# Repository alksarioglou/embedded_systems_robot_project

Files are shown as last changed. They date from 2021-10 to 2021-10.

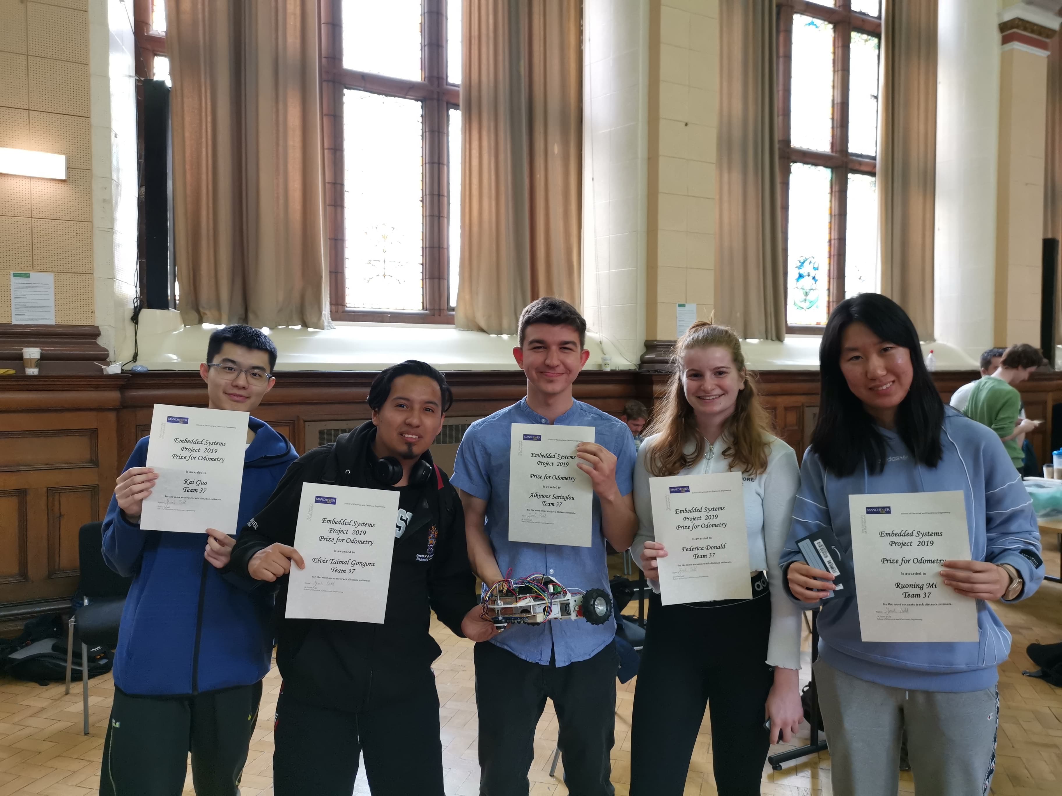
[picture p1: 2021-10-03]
Team.jpg

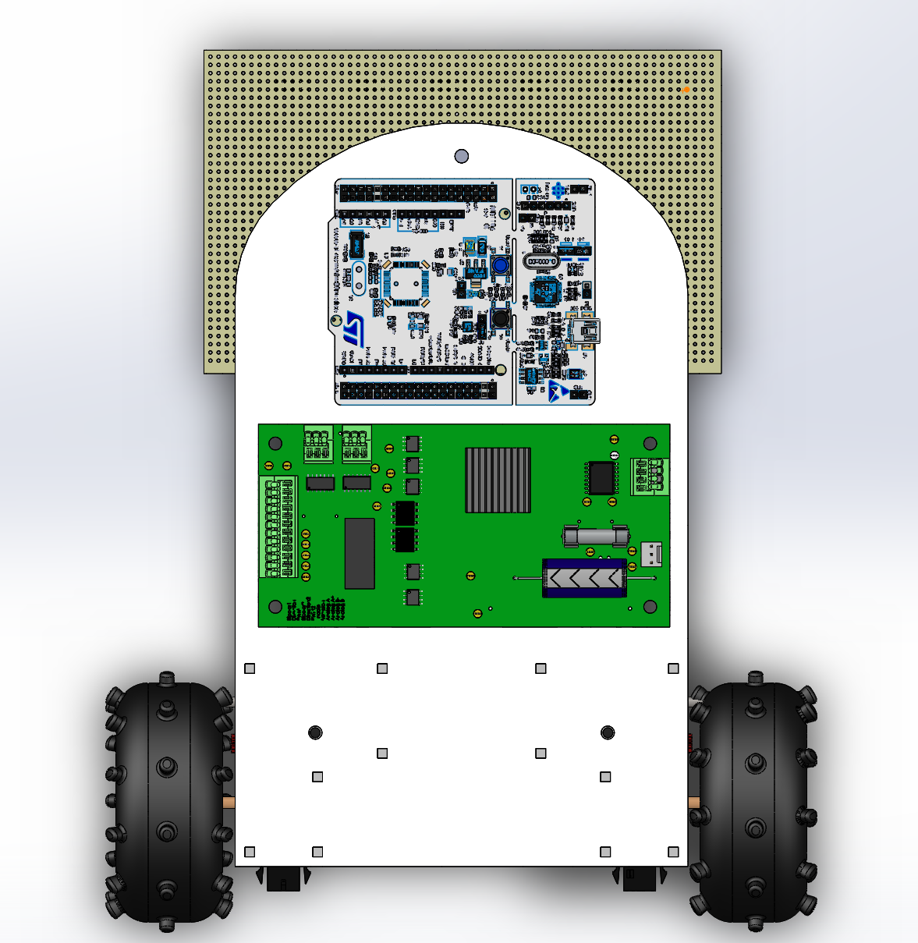
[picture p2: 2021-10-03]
Robot_CAD_Models/5.PNG

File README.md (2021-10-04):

# Embedded Systems Buggy Project
Building an autonomous robot in a team of 5 students which followed a white line on a track using reflective sensors and PID controllers by coding in **Arduino** and **C++**.

## My responsibilities
- **Team leader for both hardware and software** in a team of 5 students 
- Implemented the award-winning algorithm (**Track Length Estimation Award**) in **C++** to measure the distance covered by the robot accurately to 3 decimal places (code found in `Source Code/distancecalc.cpp`)
- Implemented the **coding of the motors, the interface of the sensors and multiple other functions such as steering, stop and turn-around** (code found in `Source Code/FinalCode - Group 37.cpp`)
- Designed the **stripboard** of the reflective sensors (stripboard implementation found in `Schematics`)
- Converted the stripboard to a **PCB** (PCB found in `PCB`)
- Created the **CAD models** for the body of the buggy (models found in `Robot_CAD_Models`)

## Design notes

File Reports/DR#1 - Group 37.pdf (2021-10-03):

## Embedded Systems Project

## DESIGN REPORT #1

## Title: Electric Motor Characterisation and Gear Ratios

## Group Number: 37

Group members name: | ID Number | I confirm that this is the group’s own work.
Alkinoos Sarioglou | 10136315 | ☒
Elvis Taimal Gongora | 10146823 | ☒
Federica Donald | 10095518 | ☒
Kai Guo | 10201372 | ☒
Ruoning Mi | 10431554 | ☒

## Tutor: Dr Emad Alsusa Date: 31/10/2018

Contents

Introduction

This report analyses the measurements taken in the motor characterisation and force laboratory, evaluates their meaning and significance to the characterisation and concludes all the measurements to recommend the final gear ratios for the buggy. This is a crucial part of the embedded systems project as the correct gear ratios must be found for our design to ensure the buggy can move around different terrains, trading off appropriately between torque and speed. A gear box uses efficient gear ratios to provide higher levels of torque for the same mass. However, the speed of the motor is reduced as torque increases so the buggy will not be able to travel around the track as quickly. Furthermore, the microcontroller current is too small to power a motor, so a motor driver is necessary to communicate with the motor and provide the higher currents needed to operate. The microcontroller produces electrical signals and the motor gets mechanical signals that cause it to move. The electrical signal that determines the motor speed is the voltage whilst the current flowing through the motor circuit effects the torque in the input shaft.

Motor characterisation

Introduction
Motor characterisation is an important part of the project as it enables the calculation of the armature resistance, brush voltage and torque constants of the motors.

Constraints on maximum voltage and current The motor drive board can supply a maximum of 1.4 A [1] restricting the values that can be tested. According to Joule’s law（Q =

V

2

R

∗ t) (Equ. 1) [2] where Q is thermal energy, the higher the voltage, the hotter the motor will be. To protect the motor, voltage was set at 5 V [1].

Test results and Calculations

### 2.3.1 Diameter of the shaft

In order to get a more accurate value of the diameter, three measurements were performed, and the average was calculated giving 9.63 mm.

### 2.3.2 Armature Resistance and Brush voltage with Motor stalled

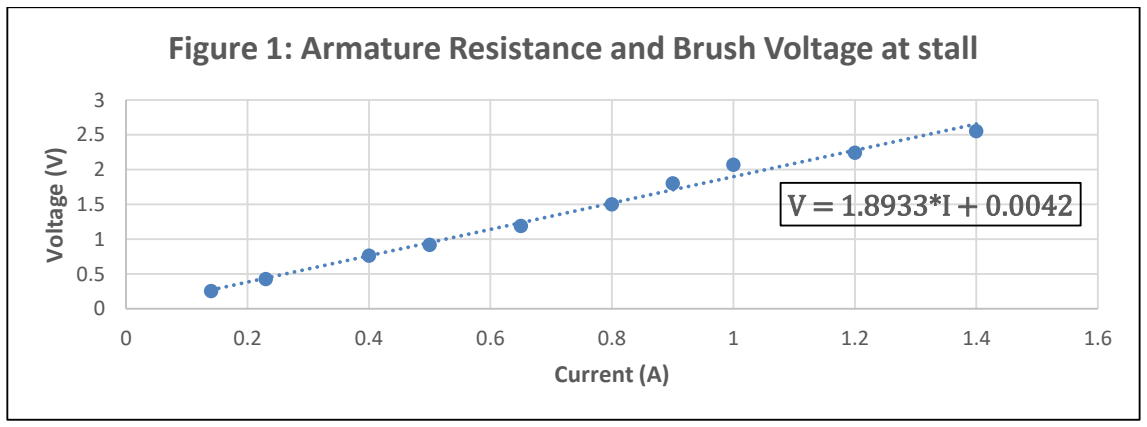
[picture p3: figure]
Voltage (V); Current (A)

### Figure 1: Armature Resistance and Brush Voltage at stall

Due to V = R ∗ I + Vb

(Equ. 2) [3] , R = 1.893 Ω and Vb = 0.0042 V.

### 2.3.3 KE and KT at a constant motor voltage

With voltage set to 5V, the forces F1 and F2 [4] and motor speed were measured. Due to T = (F1 − F2) ∗ 0.5d (Equ. 3) [4] , EMF = V − Vb − I ∗ R (Equ. 4) [5] , torque and motor EMF were found at different currents.

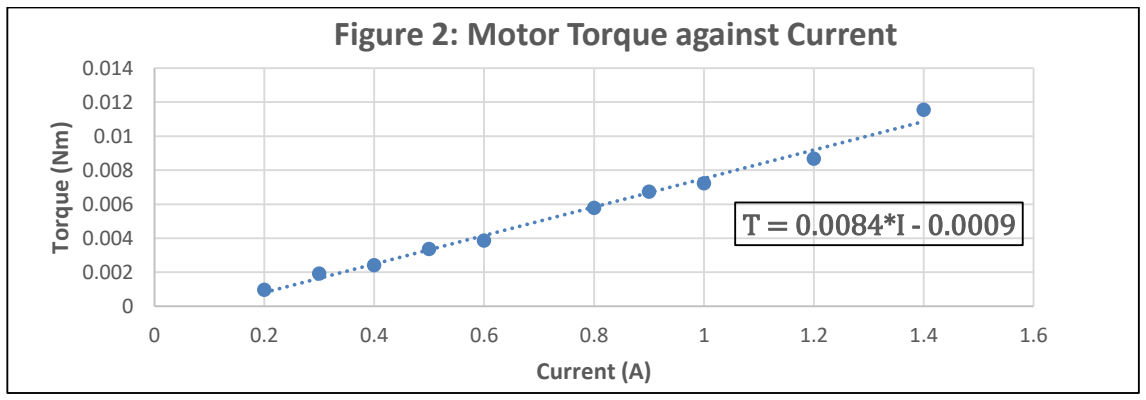
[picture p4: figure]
Torque (Nm); Current (A); Figure 2: Motor Torque against Current

Due to T = KT ∗ I – Tfriction (Equ. 5) [6], KT = 0.0084.

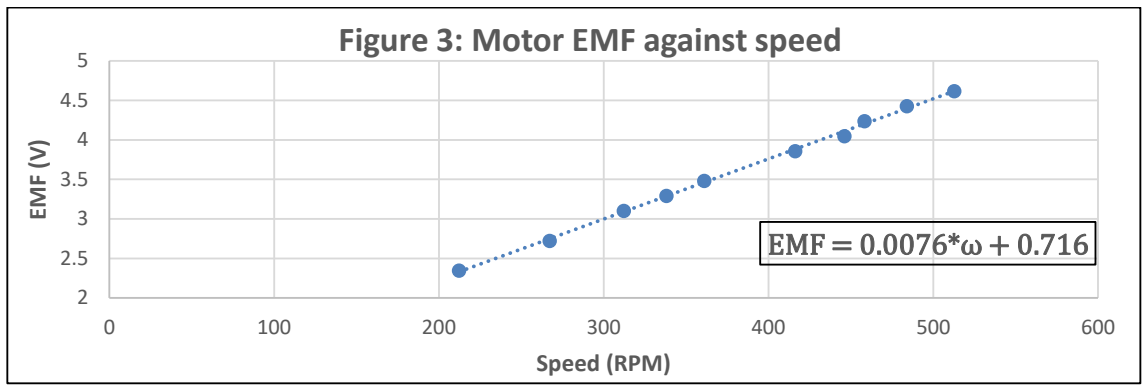
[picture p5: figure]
EMF = 0.0076*ω + 0.716; EMF (; Speed (RPM); Figure 3: Motor EMF against speed

Due to EMF = KE ∗ ω (Equ. 6) [7], KE = 0.0076.

### 2.3.4 KT and R at stall

By controlling the forces, the motor was stalled and the current was recorded. The process was repeated ten times and the values of force and current under different voltages were measured. According to (Equ. 3), the values of torque were calculated:

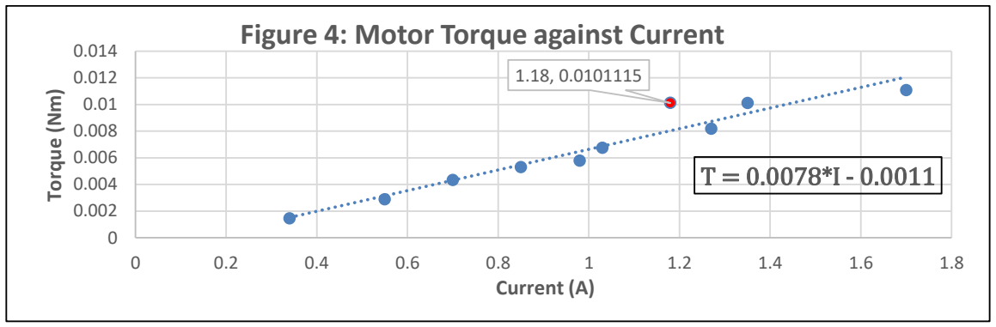
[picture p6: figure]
Torque (Nm); Current (A); Figure 4: Motor Torque against Current

Due to (Equ. 5), KT = 0.0078.

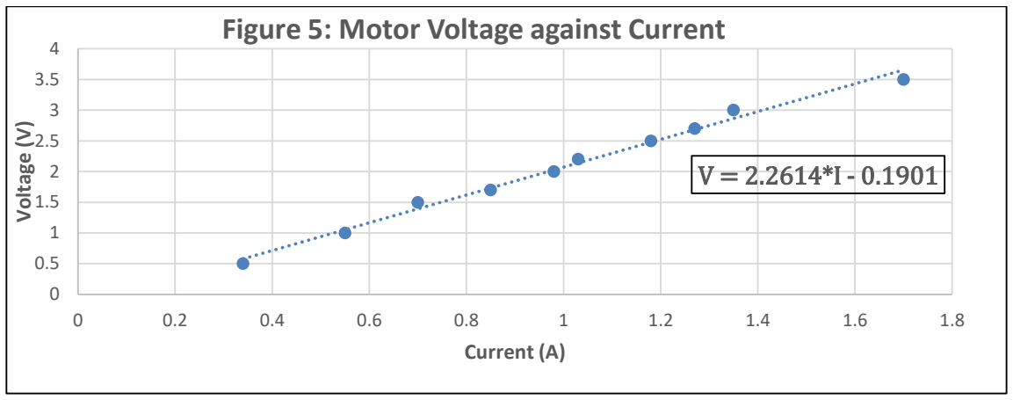
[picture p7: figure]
Voltage (V); Current (A); Figure 5: Motor Voltage against Current

Due to (Equ. 2), R = 2.2614 Ω.

Comments on the measurement accuracy

### 2.4.1 Resistance Error

There is a difference in resistance found between Figure 1, 1.893 Ω, and Figure 5, 2.2614 Ω, caused by the heating effect. The measurements presented in Figure 5 have been performed after the motor has already been used for the previous tasks. Therefore, its temperature has already increased. As a result, higher temperature in the motor results in slightly bigger resistance.

### 2.4.2 Force Error

As shown in Figure 4, the point (1.18 A, 0.0101115 Nm) deviates far from the fitting curve. The main reason for that is the inaccurate measurement of force. There are some errors resulting from not reading the force value accurately. For example, applying bigger forces than required to keep the motor just stalled, or if the perspective of reading the value is changing. In order to increase the accuracy of force measurement, digital equipment could have been used.

Load measurements

Introduction
This section will determine the forces required to move the buggy up the slope and on the flat surface. These forces depend on the mass of the buggy and on the calculation of the friction constant. From the measurements, the constant’s error is also derived. From these values of forces, the torque required at the wheel shafts is calculated leading to the selection of the most suitable gearbox.

Estimated Forces required to drive the buggy up the slope As the mass can only be estimated, a 30% error is added. The best estimate of mass is calculated using the table of mass given [8] + 100g of circuitry/wiring/stripboard: Best estimate of mass: mest = 1537 g ± 30% = 1537 g ± 461.1 g
mmax = 1998.1 g | mmin = 1075.9 g

To find the coefficient of friction, the forces in the horizontal axis must be solved (Fig.7):

∑F = m ∗ a = 0 (Equ. 7)

∑F = Fx − N = 0 (Equ. 8)

Fx = N = mest ∗ g ∗ cf (Equ. 9)

cf =

Fx
W

(Equ. 10)

From the measurements in the force lab, the mean value and the standard deviation of cf can be calculated.

cf in Flat Table 1: Friction constant | Mean | Standard Deviation | Standard Error
| 0.073354847 | 0.006898639 | 0.002816357
Hence, | cf = 0.0734 ± 0.0028
For m = mest = 1537 g:

For the friction force on the incline [9]:
N = cf ∗ mest ∗ g ∗ cosθ (Equ. 11)

The buggy needs to overcome this

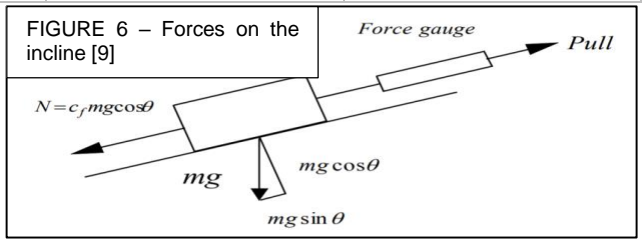
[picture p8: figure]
FIGURE 6 – Forces on the incline [9]

force and the component of weight so for the force from the motor [7]: F = N + m ∗ g ∗ sinθ (Equ. 12)
That is the total force so for each wheel in the maximum incline of 18°:

F1 =

cf∗mest∗g∗cos(18°)+mest∗g∗sin(18°)
2

=

0.0734∗1.537∗9.8∗cos(18°)+1.537∗9.8∗sin(18°) 2

= 2.853 N

For the propagation of error [10]:

We consider Fa =

cf∗mest∗g∗cos(18°)
2

(Equ. 13) and Fb =

mest∗g∗sin(18°)
2

(Equ. 14)

The error for the first part of the fraction is:
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
δmest

mest

)

2
gives δFa = 0.111 N (Equ. 15)

Similarly, for Fb:

(δFb

)

2 = (

g ∗ sin(18°)
2

)

2
∗ (δmest)

2 gives δFb = 0.789 N (Equ. 16)

So δF1 = δFa + δFb = 0.111 + 0.789 = 0.9 N (Equ. 17)
Hence F1 = 2.853 N ± 0.9 N

As a result, the maximum force that is needed for each wheel to drive the buggy up the slope is: F1max = 2.853 + 0.9 = 3.753 N

Estimated Forces required to drive the buggy on the flat surface For m = mest = 1537 g:

For the friction force on the flat surface: F = N = cf ∗ mest ∗ g (Equ. 7)

That is the total force so for each wheel:

F2 =

cf∗mest∗g
2

=

0.0734∗1.537∗9.8
2

=

1.1056
2

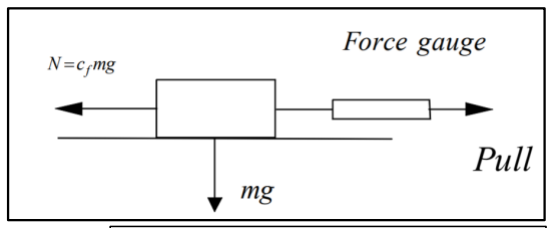
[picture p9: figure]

= 0.553 Ν (Equ. 18)

FIGURE 7 – Forces on a flat surface [9]

For the propagation of error [10]: Error for the fraction:
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
δmest

mest

)

2
(Equ. 20)

Which gives δF2 = 0.167 N
Hence F2 = 0.553 N ± 0.167 N

The maximum force needed for each wheel to drive the buggy on a flat surface is: F2max = 0.553 + 0.167 = 0.72 N

Required Torque at the wheel shafts On the ramp
For the torque for each wheel [9]: T = F1max

∗ r (Equ. 21)

where r is the radius of the wheel, r =

d
2

=

76.1mm
2

= 38.05 mm = 0.03805 m.

∴ T = 3.753 ∗ 0.03805 = 0.1428 Nm

On the flat surface
For the torque for each wheel [9] using (Equ. 21) for F2max :

∴ T = F2max

∗ r = 0.72 ∗ 0.038805 = 0.0274 Nm

Gear ratio selection

Introduction
This section is crucial for the progress of the report and the overall project. The calculations for each available gearbox are made with the aim of getting the required torque calculated in section 3.4.
The aim is to get the highest mechanical power, which is a trade-off between speed and torque. This can be achieved by finding the operating point (I and V), where the wheels gain maximum mechanical power with high speed and torque.
On one hand, high speed is needed to drive the buggy as quickly as possible, however high torque must also be considered so that the necessary force to drive the buggy up the slope will be provided.

Current and voltage required for the incline without gearbox From Figure 2 and (Equ. 5), the value of current needed for the required torque of
0. 1428 Nm is I = 17.11 A. From Figure 1 and (Equ. 2) this would result in a voltage value of 32.39 V. These values are obviously not achievable.

Available motor torque with given motor and drive board The motors will be operated at 5 V and maximum current ( 1.4 A ), hence Tin = 0.011556 Nm (Equ. 5) and ωin = 212.264 rad
s

(Equ. 6). Motor torque of 0.011556 Nm is not enough to drive the buggy up the maximum incline with the use of motors only, so a suitable gearbox must be chosen.

Calculations of torque and speed for the gearboxes The calculations of torque and speed for each gearbox are performed.
For gearbox 1:
Pinion, N1 | Intermediate N2A | Intermediate N2B | Final Drive, N3
16 tooth | 48 tooth | 12 tooth | 48 tooth

First stage
T1 = Tin ∗ (

N2A
N1
) [11] | T1 = 0.011556 ∗ (
| 48
16) = 0.03467 Nm

Assuming 85% efficiency [11]: T1eff = T1 ∗ 0.85 = 0.02947 Nm

Second stage
Tout = T1eff ∗ (

N3

N2B

) [11] | Tout = 0.02947 ∗ (
| 48
12) = 0.11788 Nm

Assuming 85% efficiency [11]: Touteff = Tout ∗ 0.85 = 0.1002 Nm

ωout = ωin ∗ (

N2B

N2A

∗

N1
N3

) = 212.264 ∗ (

12
48

∗

16

48) = 17.69 rad
s

or 168.93 RPM

For gearbox 2:
Pinion, N1 | Intermediate N2A | Intermediate N2B | Final Drive, N3
16 tooth | 50 tooth | 10 tooth | 48 tooth

First stage
T1 = Tin ∗ (

N2A
N1
) [11] | T1 = 0.011556 ∗ (
| 50
16) = 0.03611 Nm

Assuming 85% efficiency [11]: T1eff = T1 ∗ 0.85 = 0.0307 Nm

Second stage
Tout = T1eff ∗ (

N3

N2B

| ) = 0.0307 ∗ (
| 48
10) = 0.14736 Nm

Assuming 85% efficiency [11]: Touteff = Tout ∗ 0.85 = 0.1253 Nm

ωout = ωin ∗ (

N2B

N2A

∗

N1
N3

) = 212.264 ∗ (

10
50 ∗

16
48) = 14.15
| rad s or 135.12 RPM

For gearbox 3:
Pinion, N1 | Intermediate N2A | Intermediate N2B | Final Drive, N3
16 tooth | 50 tooth | 10 tooth | 60 tooth

First stage

T1 = Tin ∗ (

N2A
N1
) | T1 = 0.011556 ∗ (
| 50
16) = 0.0361 Nm

Assuming 85% efficiency [11]: T1eff = T1 ∗ 0.85 = 0.0307 Nm

Second stage
Tout = T1eff ∗ (

N3

N2B

) = 0.0307 ∗ (

60
10) = 0.1842 Nm

Assuming 85% efficiency [11]: Touteff = Tout ∗ 0.85 = 0.1566 Nm

ωout = ωin ∗ (

N2B

N2A

∗

N1
N3

) = 212.264 ∗ (

10
50 ∗

16
60) = 11.32

rad
s

or 108.1 RPM

Selection of gearbox – Required position of the intermediate shaft as an (x,y) coordinate
Gearbox 3 is the only one which produces the required torque. Hence, gearbox 3 is the selection for the buggy to go up the maximum incline of 18°.

The coordinate system and the position of the origin are shown on Figure 8.
Assuming input and intermediate
shaft | align | horizontally | and
MOD=0.5 mm [12]:

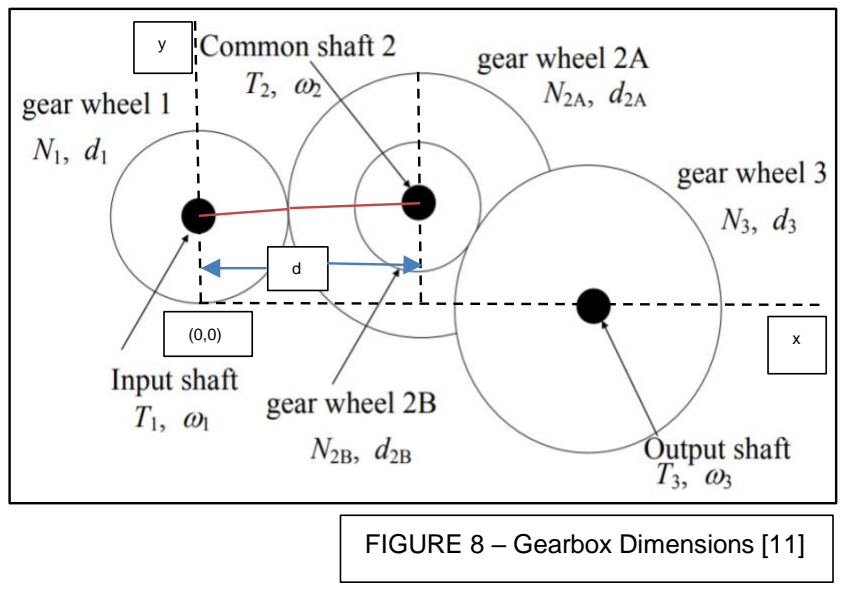
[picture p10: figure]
FIGURE 8 – Gearbox Dimensions [11]

For gearwheel 1: PCD(1) = N1 ∗ MOD = 16 ∗ 0.5 mm = 8 mm For gearwheel 2A: PCD(2A) = N2A ∗ MOD = 50 ∗ 0.5 mm = 25 mm

x co − ordinate = d =

PCD(1)+ PCD(2A)
2

+ 0.1 mm = 16.6 mm

For the y coordinate, from Figure 8: y = PCD(1) = 8 mm

Hence, the position of the intermediate shaft is (16.6, 8).

Speed of the buggy on the ramp and on the flat surface Making the calculations for gearbox 3 the output torque and the correspondent speed for each value of current is calculated.
I(A) | | Touteff(Nm) | ωout(rad⁄s)
0.2 | | 0.013045641 | 27.35288889
0.3 | | 0.026091281 | 25.81777778
0.4 | | 0.032614102 | 24.44455111
0.5 | | 0.045659742 | 23.79143111
0.6 | | 0.052182563 | 22.20049778
I(A) | Touteff(Nm) | ωout(rad⁄s)
0.8 | 0.078273844 | 19.25308444
0.9 | 0.091319484 | 18.03616
1 | 0.097842305 | 16.65176889
1.2 | 0.117410766 | 14.25141333
1.4 | 0.156547688 | 11.32074667

From Table 2, operating the motor at 0.4 A gives the required torque of 0.0274 Nm for

Table 2: Output Torque and Speed in different currents the flat surface and high speed. From the table ωout = 24.4446 rad
s

, so the speed for
each wheel [9] will be: v = ω ∗ r = 24.4446 ∗ 0.03805 = 0.9301 m
s

or 3.3484 km
h

. The
total speed of the buggy (combining two wheels) is: V = 2 ∗ v = 1.8602 m
s

or 6.6968 km
h

On the ramp:
From the previous calculations ωout = 11.32 rad
s

, so the speed for each wheel will be: v = ω ∗ r = 11.32 ∗ 0.03805 = 0.4307 m
s

or 1.5505 km
h

. The total speed of the buggy (combining two wheels) is: V = 2 ∗ v = 0.8615 m
s

or 3.1014 km
h

Summary

In conclusion, this report disposes the measurements acquired in the Motor and Force Lab to make sure that the buggy can run on different terrains. According to the graphs, the armature resistance is 1.893 Ω and the brush voltage is 0.0042 V . The torque constant (KT) is 0.0084 and the EMF constant (KE) is 0.0076 for a rotating motor while the torque constant (KT) is 0.0078 at a standstill. As it is shown, the values of the constants lie close to each other as expected. Using torque and EMF constants and assuming that the mass of the buggy is 1537 g ± 30%, the maximum force needed for each wheel is 3.753 N on the slope and 0.72 N on the flat surface. In addition, the required torque for each wheel is 0.1428 Nm on the ramp and 0.0274 Nm on the flat surface. Using torque calculations and if each gearbox has 85% efficiency, only gearbox 3 is suitable for the torque needed for the maximum incline. Hence the motors will be operated at 5 V and 1.4 A on the ramp giving an expected maximum speed of 0.8615 m
s

and at 5 V and 0.4 A on the flat giving an expected maximum speed of 1.8602 m
s

References

[1] ESP Technical Handbook p.32 – “Maximum Current”
[2] https://brilliant.org/wiki/heat-dissipated-by-resistors/
[3] ESP Technical Handbook p.33
[4] ESP Technical Handbook p.34
[5] ESP Technical Handbook p.24
[6] ESP Technical Handbook p.36
[7] ESP Technical Handbook p.22
[8] ESP Technical Handbook p.40 – Table of “Mass of buggy components”
[9] ESP Technical Handbook p.25-26
[10] Measurements and Analytical Software notes – Part 1: Measurements & Errors p.54,57,70
[11] ESP Technical Handbook p.27-29
[12] ESP Technical Handbook p.30

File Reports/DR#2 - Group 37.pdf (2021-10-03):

## Embedded Systems Project

## DESIGN REPORT #2

## Title: Technical Characterisation

## Group Number: 37

Group members name: | ID Number | I confirm that this is the group’s own work.
Alkinoos Sarioglou | 10136315 | ☒
Elvis Taimal Gongora | 10146823 | ☒
Federica Donald | 10095518 | ☒
Kai Guo | 10201372 | ☒
Ruoning Mi | 10431554 | ☒

## Tutor: Dr Emad Alsusa Date: 29/11/2018

Contents

Page 1

Introduction

This report discusses the technical characterisation and acts as a guide for the construction of the buggy in the next step. All the different aspects that will support the movement are explicitly analysed and the features that will make the buggy competitive are examined. The overall aim of the report is to shape a clear image of the final design.
More specifically, the software part discusses the structure of software in pseudo code which inspects the input response from the sensors and makes critical decisions for the movement of the buggy. Also, the ability of software to do this is strongly dependent on the line sensor responses. Therefore, the selection of the line sensors is crucial in order to achieve accurate sensing of the white line around the track. Different emitters and detectors are paired and their response is evaluated to select the best one. Additionally, the interface of these to the microcontroller is demonstrated by circuit diagrams, which clearly show how the proposed sensors are going to be connected and how the data is evaluated by software.
Depending on these data, the algorithm run by software will adjust the orientation and the speed of the buggy. For this to be achieved, different sensors are used, which output useful quantities, like speed, current and battery voltage. All of these are discussed in the non-line sensors section.
The control of the system is made possible by using a particular type of controller. All of the options offer different advantages, which are compared in the control section to decide the most efficient one. Furthermore, the control algorithm pseudo code used to implement the movement is provided.
Finally, all of the above combine to give the first representation of the buggy base with hardware design. The components which are crucial for movement and the communication of data between them are taken into consideration to design the chassis of the buggy. The deflection analysis ensures that there will be no significant bending or fracturing and the ease of manufacture of the design is also examined. Overall, the report is valuable for the progress of the Embedded Systems Project because it deals with the “intelligence” of the buggy. The controller is the “brain” that ensures the buggy will always stay on the line. Sensors are the “eyes” of the buggy, detecting the position of the line. Software supports the algorithm for controlling the motors depending on the sensors’ response. Circuitry and hardware provide the “inner body” of the buggy, making the movement possible. All of the above act as one to create a competitive buggy.

Software

Functional Summary
The software the buggy uses will monitor the position of the buggy. Also, it will send signals to the motors to change the steering of the buggy by changing the speed of the wheels. This will be done using various other sensors used to monitor
the initial speed of the motors.

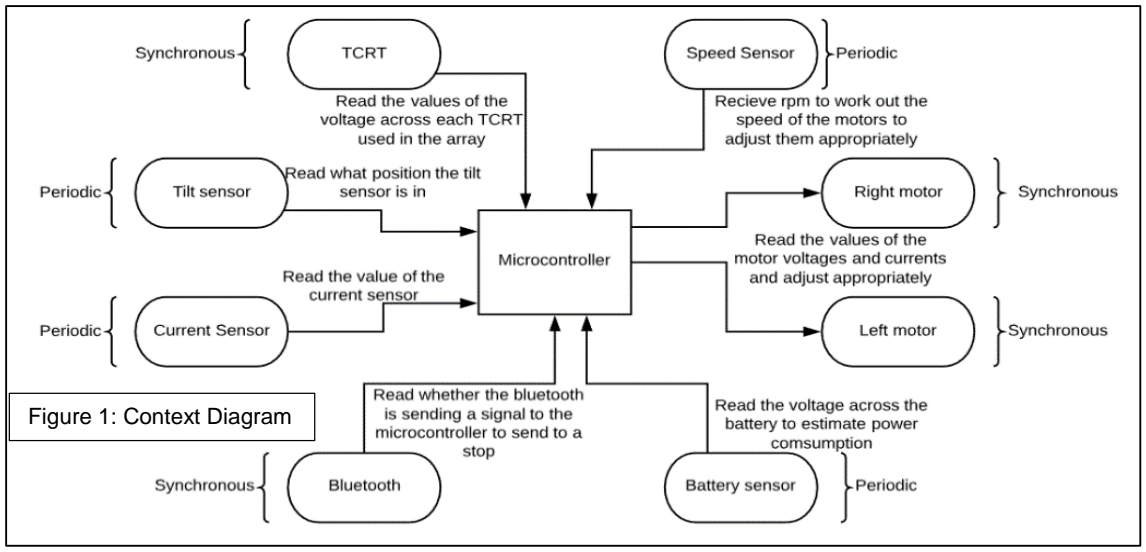
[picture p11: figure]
Figure 1: Context Diagram
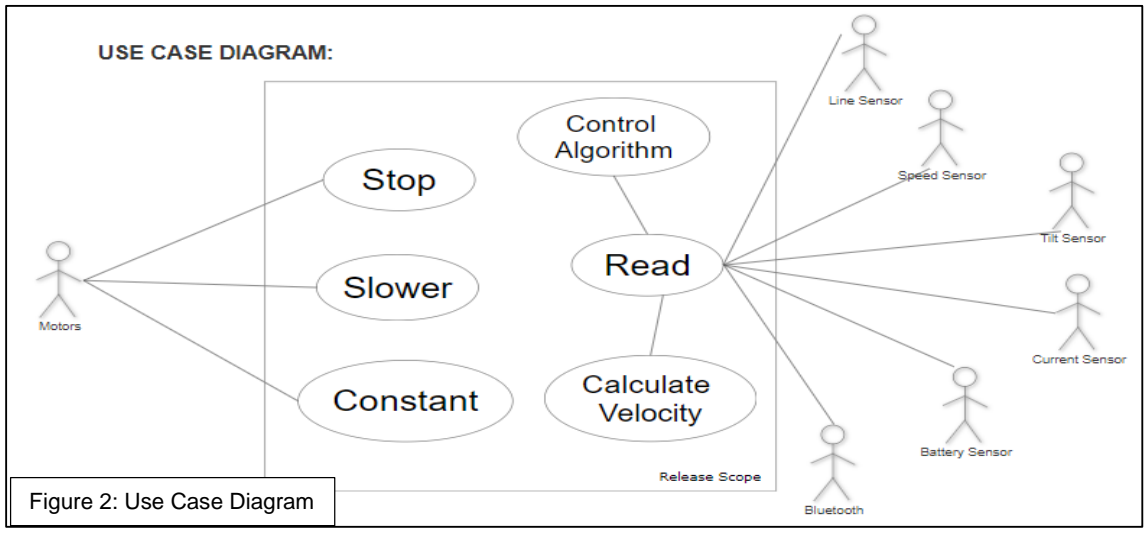
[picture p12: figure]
Figure 2: Use Case Diagram

Page 2

Constraints to the System
There are various constraints a system will encounter that will limit its functionality. These limits must be considered before writing a program. The main constraints placed on the embedded system software would relate to timing, memory and cost. Each algorithm has different execution times therefore when deciding specific algorithms, the timing should be fast so the motors act within reasonable time to turn a corner. Therefore, it is an important factor in deciding which algorithm is
chosen. The programme written must fit onto a memory constraint of 512 KB of flash and 96 KB [1] of SRAM otherwise it will not be executed as the microcontroller cannot store the programme. This is not a huge issue as the microcontroller has plenty of memory for the purpose of our program. Finally, the project has a £40 budget which will limit what extra sensors or gadgets can be added to the buggy that will maximise its functionality.

Diagrams

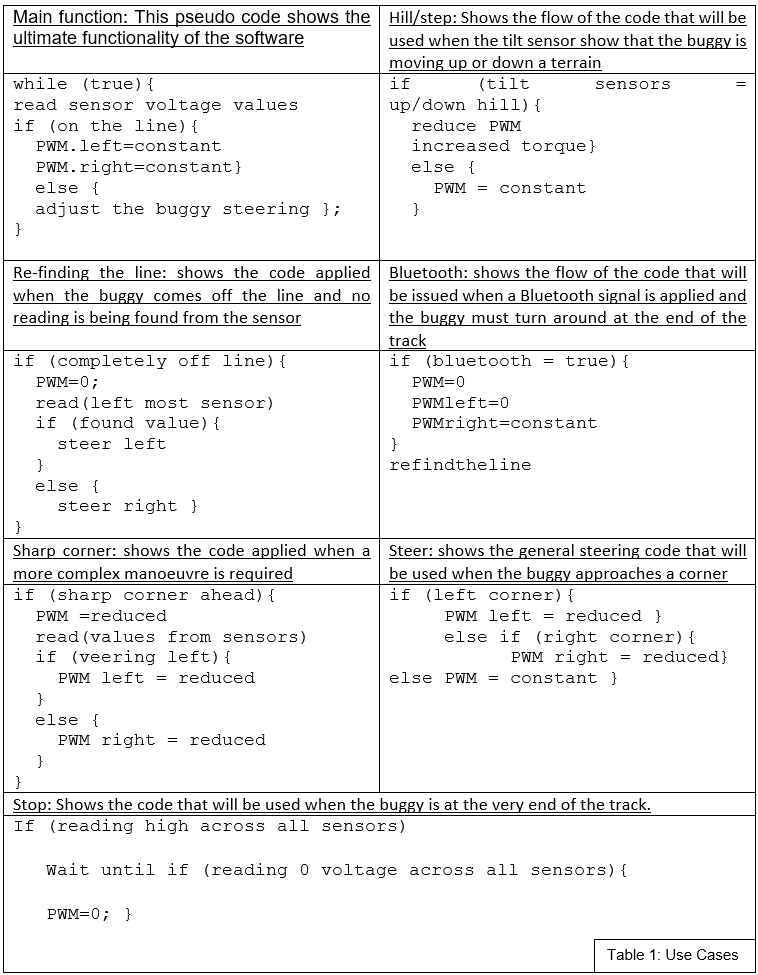
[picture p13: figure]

Page 3

The Context Diagram in Figure 1 shows the messages exchanged between the external objects and the arrival pattern of the messages. It also shows the direction of messages as it passes to or from the microcontroller.
The Use Case Diagram in Figure 2 shows the relationships between the system functions and the entities that are involved in the system. It allows designers to think further into the flow of messages, different scenarios the buggy may encounter and the data and member functions that will be required.

Use Case Descriptions

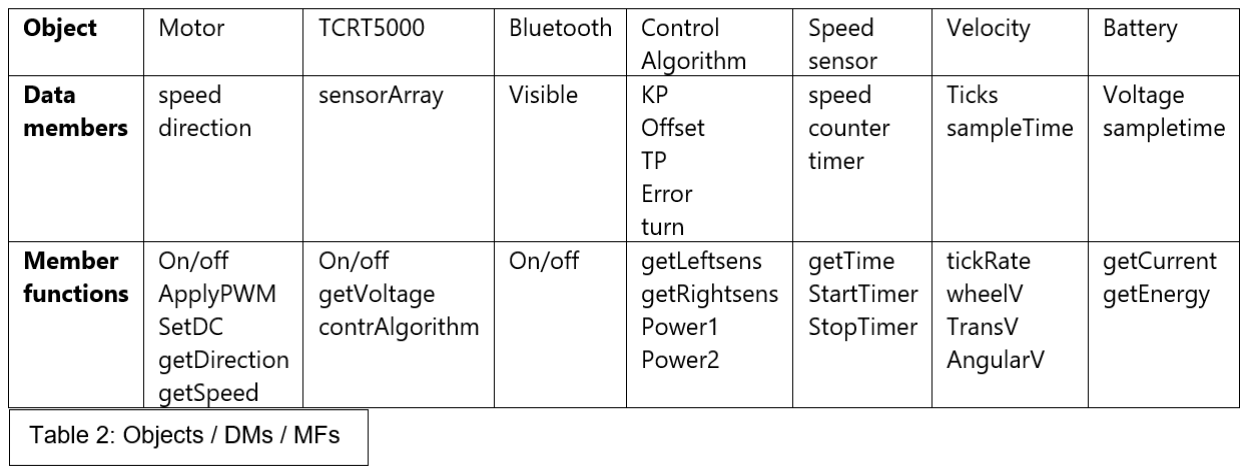
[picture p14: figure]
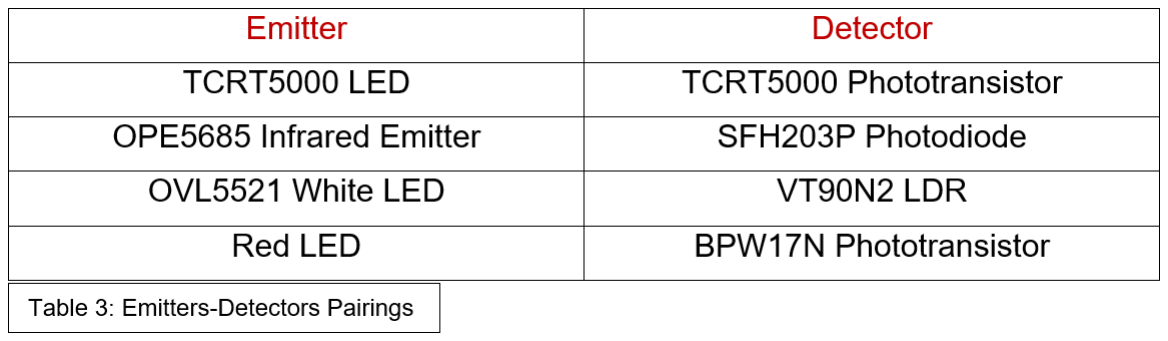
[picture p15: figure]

Page 4

Object Specifications

Line Sensor Characterisation

Introduction
In order to decide on the most suitable sensor to use for the buggy the following sensor pairings were tested:

First, the emitters with the matching detectors as well as the 8-way plugs were soldered onto a small PCB. In between them, a black barrier was placed, in order to block the direct access of light from the emitter to the detector. That is because the desired response of the detector is only the deflection of the light on the white line. That way, the system correctly decides whether the buggy is on the line. After that, the 8-way socket was soldered on the stripboard and the track next to the pins used was cut. Then, the PCB was placed on the stripboard by connecting the plugs to the socket. Next, the circuit of the sensor was created and the appropriate current-limiting resistor, according to the datasheet of the emitter, was calculated and placed on myDAQ. Four wires were soldered on the stripboard that connected it to the power supply, resistors and the ground according to the circuit diagram. The output voltage was measured across the resistor of the detector (10 kΩ) by connecting two wires to an analogue channel of the myDAQ. By using the oscilloscope from the Instruments Launcher for the myDAQ the voltage in the analogue channel was measured. The stripboard containing the sensor was fixed in the test rig at different heights and the output voltage was measured. The track was placed underneath. The distance between the centre of the line and the sensor was the varying quantity ranging from -5.5 cm to 5.5 cm. That way, the output voltages were measured and recorded in an Excel Sheet, where the graphs were plotted.

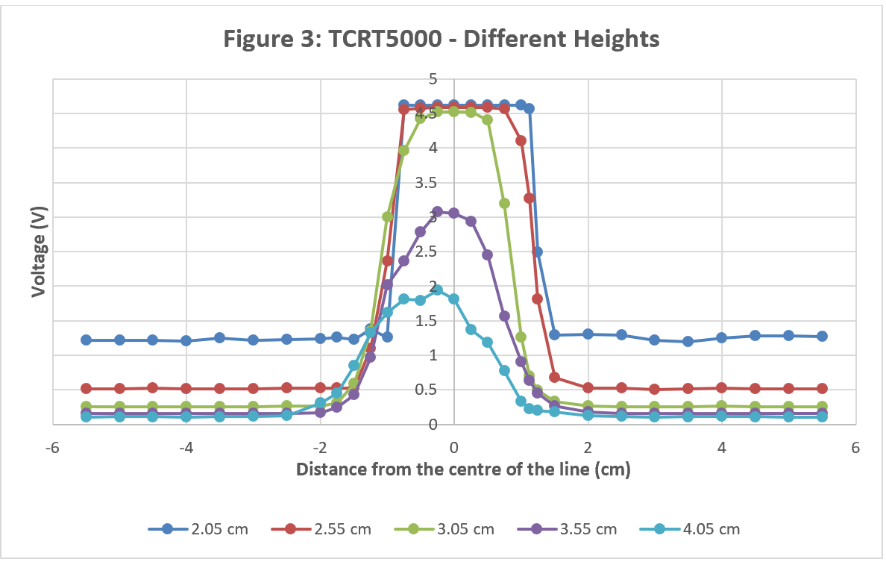
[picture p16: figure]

Page 5

Sensors Measurements

- TCRT5000 Sensor

At first, the TCRT5000 sensor with integrated LED and phototransistor was tested. According to Figure 3, the voltage at distances from -5.5 cm to -1 cm and from 1 cm to 5.5 cm (black part of the track) is constant ranging from 0 to 1.5 V depending on height. When it comes to the distance between -1 cm and 1 cm (white line), each curve increases suddenly and tends to stabilise at about 4.5 V. When the sensor is lower, the output response over the white line is maximum (2.05 cm,2.55 cm, 3.05 cm). From these three heights the most suitable is 2.55 cm as we get the most rapid increase between the white and the black line. Also, intermediate voltages are measured when the sensor is transitioning from the white to the black part. Hence, it can be seen that TCRT5000 is sensitive to detecting the white line.

- OPE5685 Infrared Emitter – SFH203P Photodiode

As it is shown in Figure 4, the OPE5685-SFH203P sensor is sensitive in the black section because the voltage curve is almost flat below 10 mV when it is at distance from -5.5 cm to -2 cm and from 2 cm to 5.5 cm. However, when it gets closer to the white line, the voltage increases rapidly at a height of 2.55 cm but is not stable when it is above the line. Meanwhile at the other heights, the voltage increase is not obvious as the increase of the response of the white line is only 10 mV to 20 mV.

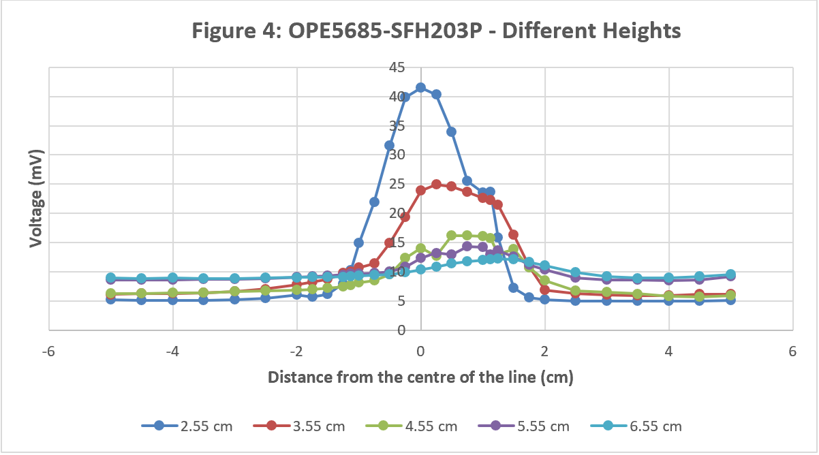
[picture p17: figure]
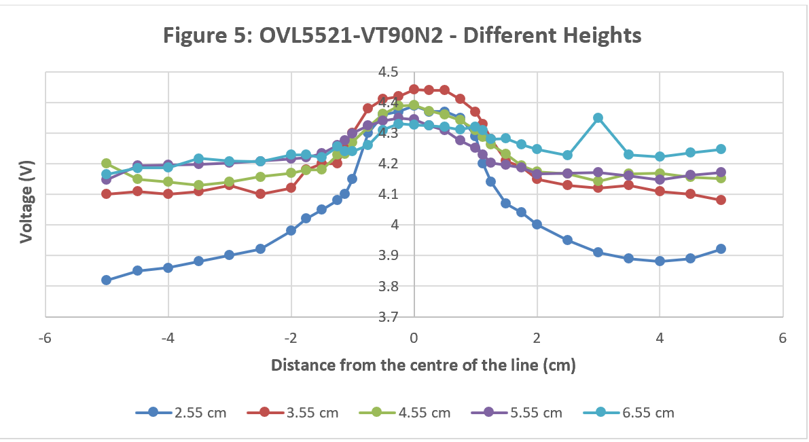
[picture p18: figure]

Page 6

- OVL5521 White LED – VT90N2 LDR

From Figure 5, the voltage curves start rising when the sensor is still on the black part. Therefore, the increase is not rapid and the buggy will not have a clear understanding of where the white line is. As the height increases, the difference between the low and high responses decreases. The high response value is not stable when the sensor crosses through the white line. This sensor would not be suitable, as the system requires a rapid change between the black and the white part and a stable value on the white line, to interpret the response of the sensors correctly.

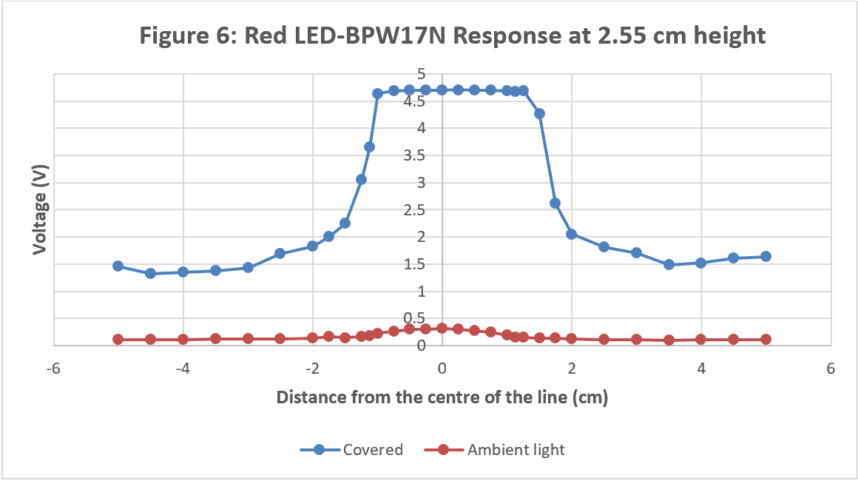
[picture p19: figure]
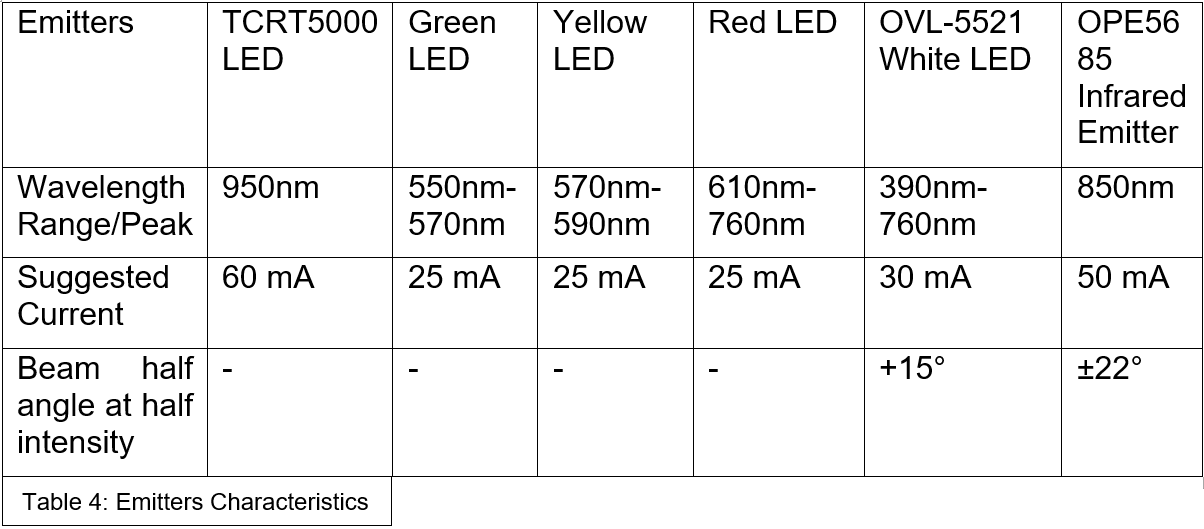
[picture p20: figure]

Page 7

- Red LED – BPW17N Phototransistor

Through this experiment, it is found that the Red LED - BPW17N pair is affected by ambient light. In Figure 6, when it is uncovered, the voltage has almost no change between the two parts. Once it is covered by a black mat, the voltage shows a clear increase when it detects the white line and is stable at about 4.7 V. However, this is not practical as no cover will be used. Hence, this is not a good sensor to use in ambient light.

Sensors Characteristics
The wavelength range of the emitters and the detectors was the main factor considered when pairing them. More specifically, the wavelength of both should be compatible, so that when the emitter emits light of specific wavelength, the detector will be able to detect it after reflection on the white line. For example, the pairing of the OPE5685 Infrared Emitter and the SFH203P Photodiode is based on the fact: the emitter emits lights of 850nm wavelength (Table 4) and the photodiode detects wavelengths in the range 400 nm – 1100 nm (Table 5). Therefore, the wavelengths are compatible. The same fact applies for the other pairs according to the tables. The datasheets give information on the characteristics:

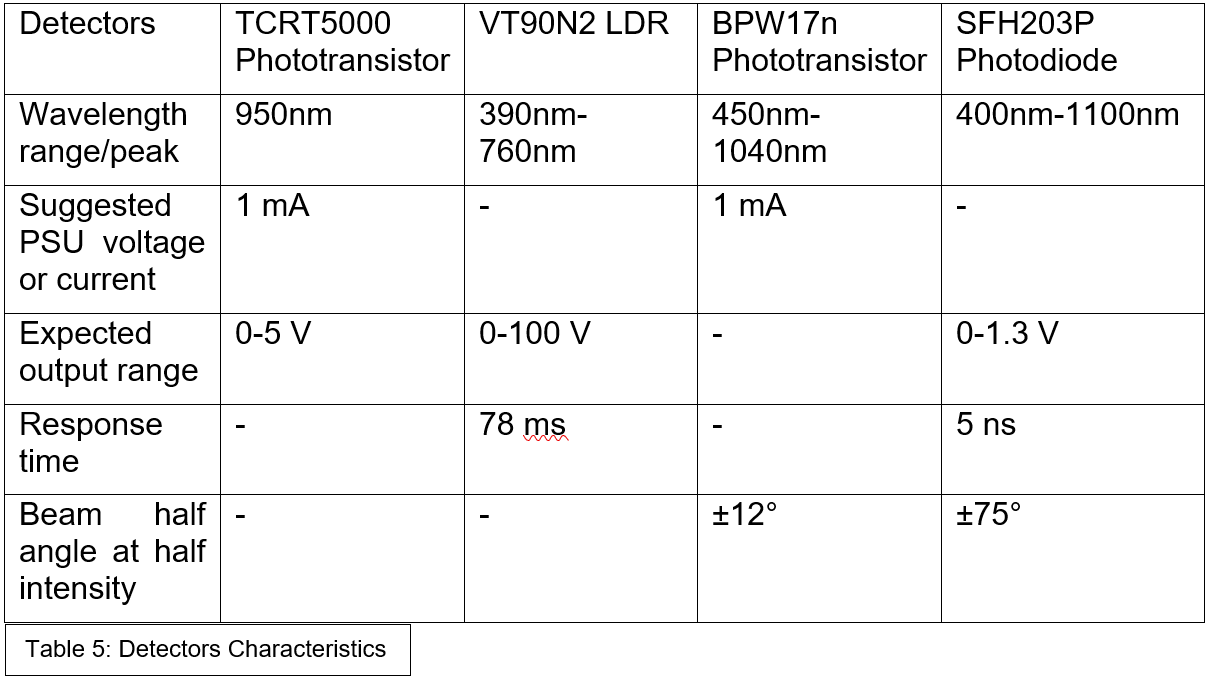
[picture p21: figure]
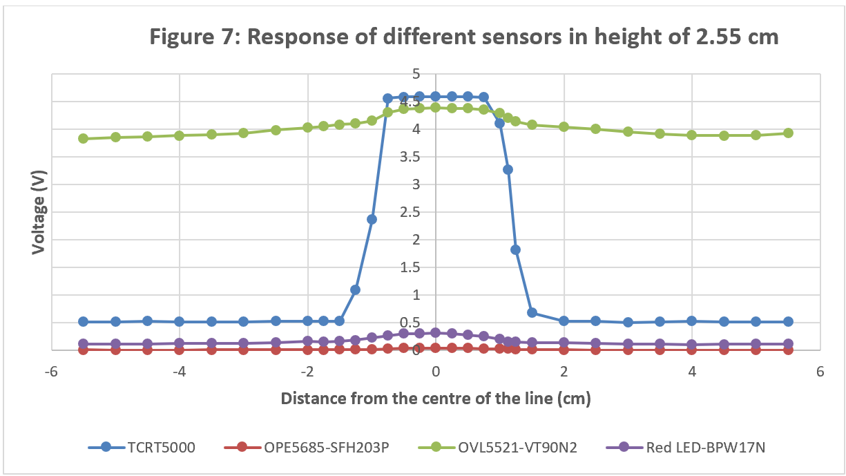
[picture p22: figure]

Page 8

Sensors comparison
By comparing at the height of 2.55 cm between 4 sensors in Figure 7, it can be seen that TCRT5000 gets a stable and large value when it detects the white line. Meanwhile it has a rapid change when the sensor transitions from the black to the white section. These values are useful for software to get a more accurate steering pattern. For these reasons, the TCRT5000 is the final choice.

Sensor Characterisation
After repeated comparisons, the final decision of the height for the TCRT5000 sensor to detect the white line is at 2.55 cm. When the sensor gets closer to the white line, the voltage increases rapidly and then tends to keep a stable value.
The appropriate value of output resistor also needs to be determined. By taking measurements for different resistor values the graph of the response can be plotted as in Figure 8. For resistor values smaller than 10 kΩ, the response of the sensor is

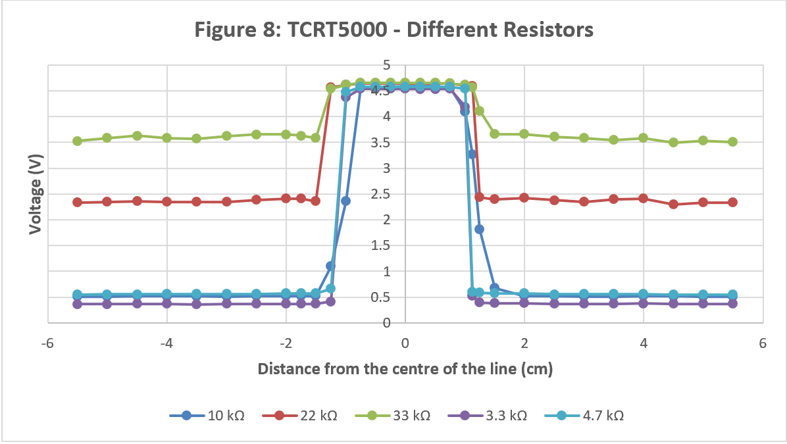
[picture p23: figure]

Page 9

rapid between the black and the white part, and in-between values are not provided. On the other hand, for resistor values bigger than 10 kΩ, the difference between the low and high output response is smaller and in-between values are not visible as well. When it is connected to the 10 kΩ resistor however, the voltage increase is more evident than the others and voltage values in-between the white part and black part are provided. As a result, the most suitable resistor value is 10 kΩ.

Direct sunlight, line-breaks and other irregularities

- For sunlight, TCRT5000 has a filter to block ambient light, therefore it can get better results than other sensors, because the direct sunlight cannot have a big effect on the output result of the sensor.
- To deal with line-breaks, the sensors will cover a wide range of the track. Through discussion, 5 sensors in an array are going to navigate the buggy around the track.
- The reflectivity of the white line will not significantly affect the output voltage, because the line will still be white enough to reflect most of the emitted light. The variation might produce an unstable output voltage, however it is still in the range of the high output voltage. Therefore, the movement of the buggy will not be affected.

Circuit Diagrams for Proposed Line Sensors

Schematic Diagram
Figure 9 shows the schematic diagrams which represent how the TCRT5000 works internally with an LED named X1 and Phototransistor named X2 and they are connected to R1 of 66.8 Ω and R2 of 10 kΩ. Αlso the second diagram uses the schematic representation of a my-DAQ.

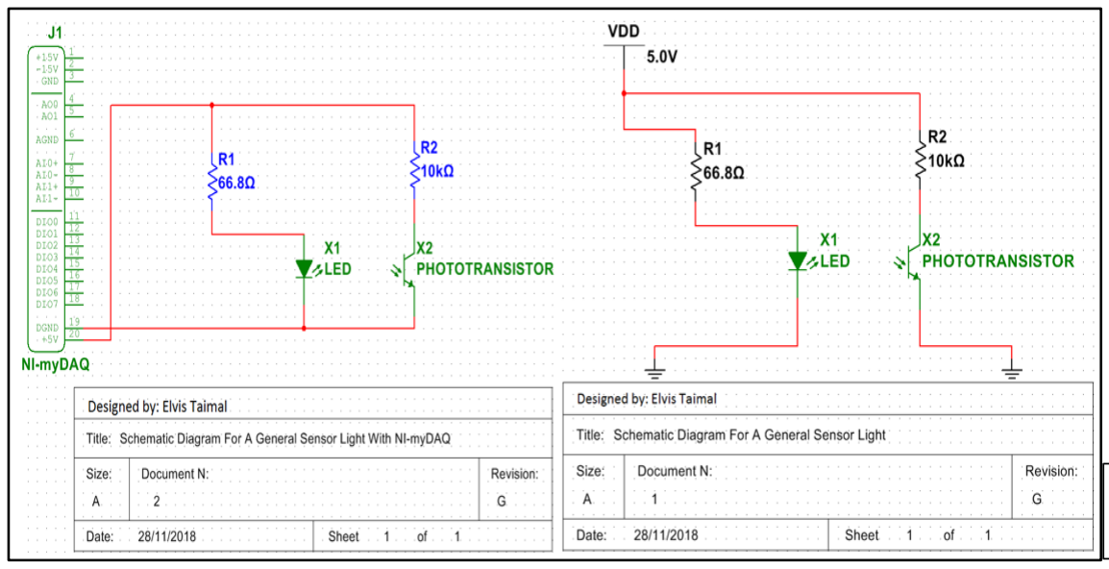
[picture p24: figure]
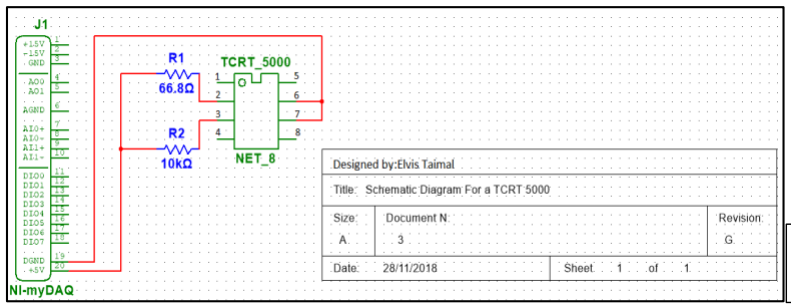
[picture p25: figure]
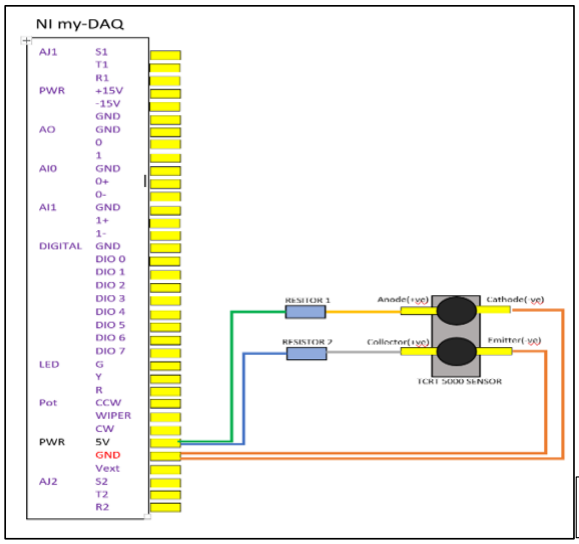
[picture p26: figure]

Page 10

Figure 10 shows the third diagram which uses an 8-pin integrated circuit to represent the TCRT5000 sensor making it easier to identify the pins.

Similar diagrams apply for all the sensor pairings but with different current-limiting resistors with the emitters and detectors mentioned in Section 3.1.

Wiring Diagram

The wiring diagram shows how the devices are connected with each other without knots or unions between cables with colour-coded wires.

Figure 11: Wiring Diagram
for TCRT5000

Figure 9: Schematic
Diagrams for TCRT5000

Figure 10: Schematic Diagram with 8-way plug

Figure 13 [2]: Nucleo Board

Page 11

Stripboard Diagram

The stripboard diagram shows how the 5 TCRT5000 sensors will be used for the buggy and how they will be connected to the 5 V source and to the microcontroller through a socket. The track will be cut between the sensors to avoid short circuits. The components representation on the diagram is:

The socket will be of a single line package where pin 1 is connected to the 5 V source, pin 2 is connected to the GND and pin 3-7 to the collectors of the respective line sensors (IC2-IC6). These connections give the voltages across the 10 kΩ resistors. These values are required for the control algorithm to control the position of the buggy.

Connections with Nucleo-F401RE Microcontroller Board

The buggy will use the Arduino connector CN6 for 5 V power-supply (pin 5) and GND (pin 6). Arduino connector CN8 will be used to connect the sensor outputs to the microcontroller analogue-in channels using the pins 1-6 which link to the ADC. The voltage read by these pins will be the voltage across the 10 kΩ resistors of the phototransistors’ collectors.

Figure 12: Stripboard
Diagram for
TCRT5000 Geometry

*White rectangles
showing resistor labels

Page 12

Non-Line Sensors

Introduction
There are 5 types of sensors which will be used for the buggy to improve functionality and competitiveness.

Speed Sensor
Firstly, it is possible to use two speed sensors, an encoder or a quadrature encoder. The quadrature is more advanced as it tells the speed and the direction of the buggy whilst the encoder only measures speed. Each gearbox is fitted with this sensor and outputs a pulse every full rotation the wheel makes. However, the index channel must be fitted individually. The best way of implementation is using a start/stop timer to measure the time of a rotation as well as a counter to count how many times it has rotated. This will have to be a near continuous examination of speed as the speed will change when moving across other terrains. There is a built-in Quadrature Encoder Peripheral (TIM2 (CH1, CH2) and TIM5 (CH1, CH2)) that can be used to interface the sensor with the microcontroller with resolutions of x2 or x4 [3].

Battery Monitor
Secondly, a battery monitor using a Dallas integrated circuit can measure voltage and accumulated current of the battery. By sampling the current at specified intervals and summing them together (presuming voltage is constant) the result is given by
E = ∫ V(t)I(t)dt [4]. To implement this in the microcontroller the code provided on blackboard will be used.

Current Sensor
Thirdly, the current across the motors can be measured to understand how much torque is being applied and whether to adjust the current if going up and down a hill. There is an isolating circuit on the motor driver board used to measure the current in each motor, amplify and send the outputs to the microcontroller to work out the total output voltage measured between test points TP18 and TP20 for motor A and TP19 and TP21 for motor B [5].

Bluetooth
Finally, Bluetooth will be used to aid the turnaround of the buggy when it reaches the end of the track. It is a short distance module that operates at 2.4 GHz [6]. GAP defines the role of the BLE to decide whether it is visible to other devices during its running. To implement this to the microcontroller the BLE module has a UART serial port [7].

Tilt Sensor
Another sensor that could aid the competitiveness of the buggy is the tilt sensor. It consists of a rolling ball and a conductive plate. Essentially when the terrain changes, the ball rolls onto the conductive plate allowing current to pass through [8]. This is used when going up and down a hill and tells the microcontroller what incline the buggy is in. This can make the buggy go up the hill at a more competitive speed by increasing the duty ratio of the PWM. This sensor being used in junction with the


Page 13

current sensor allows proper calculation to be made of how much torque needs to be applied to get up the hill in the fastest time. The advantages of this
sensor are the “built-in (1 ms) hardware debounce” [9] arrangement. To interface with the microcontroller it needs to be connected to a digital-in input pin as it outputs logic high and logic low [10]. However, it is polarity sensitive therefore it must be connected properly or will damage the circuit. Two of these sensors will be used with opposite implementation for uphill and downhill respectively.

Control

Introduction
The position of the line is specified by the difference of light that the sensors detect on each side of the buggy. For example, if the sensors on the right side of the buggy detect more light than the left ones, that means there is a right turn ahead. In that case, a controller is needed to supply less power to the right motor to make the buggy turn right and stay on track.

Comparison of Different Controllers Three types of controllers are taken into consideration. The first is Bang-Bang Controller, which is a feedback controller that switches abruptly between two states [11]. Although it is simple to use, it cannot provide smooth shift between different states, which will cause the vehicle to zigzag across the line [12]. Therefore, this is not ideal for the buggy.
The second is Proportional Controller. Compared with the former one, it is more effective because it can offer rapid corrections and responses.
The last one is the Proportional-Integral-Derivative Controller (PID). Theoretically, this is the best one because it has a proportional(P) term to correct the current errors, integral(I) term to correct past errors and derivative term(D) to correct future
errors. However, it will amplify any noise on the sensor measurements [13].
Based on the above consideration, Proportional Controller is chosen for the buggy.

Proposed Sensor Implementation

Figure 14:
Sensors
Geometry


Page 14

Figure 14 shows the proposed geometry of sensors on the buggy and their position to the line. The five blue rectangles (number 1 to 5) represent the five TCRT5000 line sensors and the two red lines are the edges of the white line. Sensor 3 is put in the center to make sure the buggy is on the line. Sensors 2 and 4 are responsible for detecting the direction change of the line. And sensors 1 and 5 are used to prevent the effect of line breaks since they are far from the line. Since we use TCRT5000 line sensors and they have filter to block sunlight, the effect of sunlight is not considered. As discussed in Line Sensor Characterisation section, the sensors will be placed 2.55 cm above the white line. The sensors are connected to the microcontroller through pins PA1 to PA5.

Proposed Control Algorithm As mentioned before, Proportional Controller is used to control the direction of the buggy. The controller continuously gets analogue voltage values from the sensors and uses proportional transition to convert it into power change for the motors. Using the control algorithm, the PWM of the motors will be adjusted. The proposed algorithm is shown below:

Hardware Overview

Introduction
This section provides the hardware specifications of the buggy. The aims are to design the chassis, considering how all the components will fit on as well as ensuring robustness and effective communication between components.

Chassis

- 2D Chassis Design

The chassis is designed on SolidWorks 2017 Edition and is shown in Figure 15.
As it is shown, the chassis is composed of one layer of Acetyl. The semicircle allows the adjustment of the components and wiring on the chassis without getting cut on a sharp edge. The holes connect it to components like the microcontroller board/break out board, the motor drive board and the gearboxes.


Page 15

The mass of the chassis, according to the SolidWorks Mass Properties is expected to be 109.11 grams.
This design is simple and has sufficient surface area to hold all the components required for the movement of the buggy both on the upper-side and the underside. Additionally, other holes can be drilled later in case something else needs to be attached on it. The choice of two layers of material has been avoided due to increased mass and therefore reduced speed.
- 2D Drawings

The detailed 2D drawing of the chassis, including all the dimensions in mm and in scale 1:2, is shown in Figure 16.
The track specifications [14] pose limitations on the design dimensions. Therefore, the width of the chassis is 14 cm, so that it will be able to make turns without touching the barriers.
The chassis is connected to the gearboxes with screws through the 4.1 mm holes and they will be attached with the help of the square holes. The microcontroller will be attached with screws through the 3.48 mm holes and the motor drive board with screws through the 4 mm holes. A thickness of 3 mm is chosen, as it will reduce the weight. The robustness is evaluated using stress analysis.

Figure 15: 2D Chassis Design


Page 16

Deflection / Stress Analysis

Figure 16: 2D Drawing

Figure 17: Stress Analysis | Figure 18: Deflection Analysis


Page 17

Deflection is an important aspect when considering a hardware design like the chassis of the buggy. The load will cause displacement and stress on the base. It is crucial that the deflection is insignificant when compared to the thickness and that the maximum stress is smaller than the yield strength. If not, the chassis is likely to significantly bend or break.
The loading that the base is subject to is 491 g, which includes the battery pack (265 g), the motor drive board (53 g), the microcontroller (35 g), its breakout board (38 g) and wiring (100 g). The weight on the base will be uniformly distributed, so the μC board will be placed at the front, the battery pack underneath and the motor drive board in the middle. The analysis is performed with a distributed mass of 0.491 kg. In Figure 17, the value of maximum deflection is low, i.e. 0.01 mm and indicates that the chassis is not likely to bend significantly or break. In Figure 18, the maximum stress value is much smaller than the value of yield strength, so the material is not likely to yield.
The stress analysis results are the expected as they are influenced by the properties of the chassis, like Acetyl’s high Young’s Modulus, high area moment of inertia [15] but also by the light load on it. In the values derived, there is a percentage of error, as in the real chassis the load cannot be perfectly distributed and the overall load might be slightly heavier, however even this will still not produce enough stress to yield the chassis. Hence, the design will be robust, light and will not break when subject to the components’ load.

Material Choice

- Comparison of Different Materials

The different material choices are evaluated in the following table:

Acetyl is generally easily accessible and is mass produced by many suppliers around the UK. This means that its cost is low (£0.019 per cm³
) compared to the other
alternatives. Furthermore, Table 7 shows that Acetyl has the lowest density and that means it can be cut more easily with lower power consumption than the other materials. Also, for the same volume of chassis it will be the lightest material to use. As far as the technical characteristics are concerned, the flexural strength gives the maximum load that the base can be subject to.
For the flexural strength [17]:

Page 18

σ =

3WmaxL
2bd

2

(1)

Where σ is the flexural strength (Pa), Wmax is the maximum load (N), d thickness (m), b width (m), L distance (m) between the two gearboxes which act as support bases.

Hence, the maximum load that the 3mm Acetyl base can cope with is:

Wmax =

2σbd

2
3L

=

2 × 91 × 10⁶ × 230 × 10⁻³ × 9 × 10⁻⁶
3 × (115.2 − 24.8) × 10⁻³ = 1389 N or 141 kg

Therefore, a base made from Acetyl enables all the components to be put on it without any yielding. As a result, a higher flexural strength is not required.

- Material Selection

In conclusion, the accessibility, low cost, low density and high flexural strength of Acetyl make it the best choice for the chassis. With this material it is ensured that the chassis will be able to hold all the components required and will be robust and light, which will increase the speed.

Ease of manufacture
The manufacture of the chassis does not pose any particular difficulty as the design is relatively large and without minute details or sharp edges, which might cause inaccuracies. Therefore, the laser-cutting machine can identify the dimensions easily and produce the required results quickly. The material does not add any difficulty to the manufacturing process, as it is the most common to laser-cut. The small size of the holes can also be achieved by the accuracy of the machine.

Drivetrain / Layout
The drivetrain of the buggy is rear-wheel drive because the power from the motors is transferred to the wheels at the back. At the front, the ball castor supports the steering. Rear-wheel drive will make steering more efficient and will also improve acceleration and braking [18]. The layout of the wheels is shown in Figure 19.


Further Hardware Thoughts
A final point refers to the wheels position. They will have the same distance from the center of the chassis so that the steering is smooth in both right and left direction.

Figure 19: Wheels Layout

Page 19

Also, the wheels are attached close to the chassis so that the distance between them is minimum. That way, the steering is faster than in a case where the wheels are placed further apart [19].

Summary

Concluding this report, important findings were derived which characterise fully the functionality of the buggy. The results and the conclusions give a clear image of how the buggy will look but also how each aspect of the structure participates to make successful movement around the track possible. Each section is summarised:

- Software: The constraints of the system do not pose any serious limitations on the progress of the project. All the possible functions and objects for the movement are now known and provide a useful guide for writing the actual code.
- Line Sensor Characterisation: Following the comparison of the different sensors, the TCRT5000 is the selection of the line sensor. A full characterisation of the proposed sensor includes the most suitable height, which is 2.55 cm and also the appropriate output resistor of 10 kΩ. The integrated daylight blocking filter will deal with direct sunlight and change in reflectivity of the white line. The configuration of the sensors (5 in a straight array) will deal effectively with the line breaks.
- Circuit diagrams: The diagrams provide a useful guide to connect the sensors to the microcontroller in the next step. The pins used are PA1 to PA5, which are analogue-in channels.
- Non-line sensors: The implementation of the non-line sensors is now known to be taken further in the next step. The buggy will be more competitive with the use of tilt sensors which will sense when it runs on an incline, in order to adjust the torque.
- Control: The rapid correction and response of the Proportional Controller make it the most suitable option for controlling the speed of the motors and the direction of the buggy. The control algorithm is now completely defined and ready to be taken to the next level. The proposed geometry includes 5 TCRT5000 sensors in a straight array.
- Hardware: The final design of the chassis is now ready for manufacture. The dimensions of the chassis adapt with the specifications of the track. A fully-dimensioned drawing is produced. On the base, all the components will be attached with screws through holes. The stress analysis indicates a maximum deflection of 0.1 mm and a small value of stress, which ensures the robustness and low weight of the chassis. The material is chosen to be Acetyl, as this will pose no difficulty in the process of manufacture. The drivetrain of the buggy is characterised as rear-wheel drive and the wheels will have the same distance from the centre of the chassis with minimum distance between them. This will ensure effective control of the buggy.
All the above conclusions demonstrate that the buggy is now fully characterised and a good performance around the track is expected.

Page 20

References

[1] | ST | life | Augmented. | (2015, | Jan). | STM32F401xD | - | xE. | Available:
https://www.st.com/resource/en/datasheet/stm32f401re.pdf , p.1
[2] ST life Augmented. (2017, Dec). UM1724 User Manuals. Available: https://www.st.com/content/ccc/resource/technical/document/user_manual/98/2e/fa/4b/e0/82/43/b7/DM00105823.pdf/files/DM00105823.pdf/jcr:content/translations/en.DM 00105823.pdf (https://www.st.com/content/ccc/resource/technical/document/user_manual/98/2e/fa/4b/e0/82/43/b7/DM00105823.pdf/files/DM00105823.pdf/jcr:content/translations/en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) , p.30
[3] Podd. F, Apsley. J, “Measuring Encoders with the STM32F401RE”, in Embedded System Project: Technical Handbook, University of Manchester, 2018-2019, p.66
[4] Podd. F, Apsley. J, “Battery Monitor”, in Embedded System Project: Technical Handbook, University of Manchester, 2018-2019, p.75
[5] Podd. F, Apsley. J, “Current Sensing”, in Embedded System Project: Technical Handbook, University of Manchester, 2018-2019, p.74
[6] Podd. F, Apsley. J, “Bluetooth”, in Embedded System Project: Technical Handbook, University of Manchester, 2018-2019, p.69
[7] Podd. F, Apsley. J, “HM-10 BLE module”, in Embedded System Project: Technical Handbook, University of Manchester, 2018-2019, p.72
[8] EL-PRO-CUS. (2018). Understanding about Tilt Sensor, Types and Working with Applications. Available: https://www.elprocus.com/tilt-sensor-types-working-principle-and-its-applications/ (https://www.elprocus.com/tilt-sensor-types-working-principle-and-its-applications/)
[9] Abra Electronics (2018). SENS-39 Golden Angle Ball Switch Tilt Sensor Module -SW520D. Available: https://abra-electronics.com/sensors/tilt-sensors/sens-39-one-way-tilt-sensor-sens-39.html (https://abra-electronics.com/sensors/tilt-sensors/sens-39-one-way-tilt-sensor-sens-39.html)
[10] HK Shan Hai Group Limited (2018). Tilt Sensor Module. Available: https://components101.com/sites/default/files/component_datasheet/Tilt%20Sensor %20Datasheet.pdf (https://components101.com/sites/default/files/component_datasheet/Tilt%20Sensor%20Datasheet.pdf)
[11] Wikipedia (2018). Bang-Bang Control. Available: https://en.wikipedia.org/wiki/Bang%E2%80%93bang_control
[12] Podd. F, Apsley. J, “Bang-bang with Deadzone”, in Embedded System Project: Technical Handbook, University of Manchester, 2018-2019, p.77
[13] Podd. F, Apsley. J, “PD or PID in Detail”, in Embedded System Project: Technical Handbook, University of Manchester, 2018-2019, p.81
[14] Podd. F, Apsley. J, “Track specification”, in Embedded System Project: Procedures Handbook, University of Manchester, 2018-2019, pp. 6-7
[15] Podd. F, Apsley. J, “Chassis Construction”, in Embedded System Project: Technical Handbook, University of Manchester, 2018-2019, pp. 84-85
[16] RS Components, Metals4u. (2018, Nov). Available: https://uk.rs-online.com/web/p/solid-plastic-sheets/0824654/https://www.metals4u.co.uk/mild-steel/c6/sheet/c2240/sheets/c55/3mm-thick/p2501
[17] L. Johnson. (2018, Nov. 05). How to Calculate Flexural Strength. Available: https://sciencing.com/calculate-flexural-strength-5179141.html
[18] Buy Here Pay Here USA. (2017, Aug. 31). Front-Wheel Drive vs. Rear-Wheel
Drive | Pros & Cons. Available: https://www.buyherepayhereusa.com/blog/front-
wheel-drive-vs-rear-wheel-drive-pros-cons/ (https://www.buyherepayhereusa.com/blog/front-wheel-drive-vs-rear-wheel-drive-pros-cons/)
[19] Podd. F, Apsley. J, “Calculating Velocity”, in Embedded System Project: Technical Handbook, University of Manchester, 2018-2019, p. 68

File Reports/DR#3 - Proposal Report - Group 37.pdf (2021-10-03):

## Embedded Systems Project

## DESIGN REPORT #3

## Title: Proposal Report

## Group Number: 37

Group members name: | ID Number | I confirm that this is the group’s own work.
Federica Donald | 10095518 | ☒
Alkinoos Sarioglou | 10136315 | ☒
Elvis Taimal Gongora | 10146823 | ☒
Kai Guo | 10201372 | ☒
Ruoning Mi | 10431554 | ☒

## Tutor: Dr. Emad Alsusa Date: 07/02/2019

Contents

Introduction, Aims and Objectives

The Embedded Systems Project is a great opportunity to be an active part of a team designing and constructing a technological system. This process poses many challenges on the way. However, a well-constructed team will be able to effectively overcome these difficulties and gain valuable experience in the field of engineering project management. The members can develop both technical and personal skills. On one hand, skills in software design, circuit design, DC motors, control algorithm and many others can be greatly enhanced. On the other hand, experience in project management, teamwork, leadership, communication is also gained, giving an accurate idea of what is like to work in the engineering industry.
All the above are achieved by working towards the main aim of the project: To construct a buggy that can follow a white line around a track in the best time possible. To fulfil the technical requirements of the project, knowledge acquired during the first year and the topics covered in the second year of the course will be used. To accomplish this, a clear schedule needs to be designed with well-allocated tasks for the members of the team. For maximum efficiency to be achieved tasks are allocated according to each member’s skills. This schedule includes many deliverables over time, which will ensure that all the small parts composing the system are well-designed and fully-functioning in order to shape a successful assembly. These deliverables include:
- Reports
- CAD Design
- PCB Design
- Motors working
- Sensors working
- Buggy Assembly
- Successful movement/steering
- Code development

Moreover, the upcoming milestones of the project can be summarized as:

- Motor Control Demo
- Sensors Demo
- PCB Fabrication Submission
- Steering Demo
- Heats
- Final Report
- Race Day

The proposal report represents an important part for the development of the project. It gives a good summary in the work that has been done until now and the objectives that have been delivered while also setting new goals. A carefully constructed report will result in a good guide for the implementation and delivery of the project.
Firstly, the technical overview gives an extensive summary of all the technical specifications of the buggy. The aim is to demonstrate the functionality of all the parts of the system, both hardware and software. Another important part of the project is the organisation of the team. This part gives insight into the roles and responsibilities of each team member along with the means of interaction and communication to guarantee the progress of the project.
As a final point, the planning and schedule of the second semester is introduced with a Gantt Chart. This tool helps in organising tasks over the second semester but also allows monitoring of the progress of each stage in a timeline representation. Furthermore, the possible risks and setbacks that may occur during the Final Race Day are evaluated in a Health and Safety Risk Assessment. It is explained who or what could cause them and how to prevent them to make sure that everyone stays safe. Finally, an estimate of the cost of the project is calculated and therefore the financial sustainability of the project is evaluated.
At this point of the project, a clear image of the buggy is shaped and shown in the following CAD pictures:


Figures 1 and 2 show how the components are placed on the designed chassis of the buggy. More specifically, the microcontroller with the motor drive board are placed on top to ensure effective communication with the sensors and the motors, while the batteries are placed underneath to save space. Finally, at the front of the buggy the castor ball with the straight array of the sensors will be placed allowing it to detect the white line.
The effective collaboration between the team will ensure the above design will be implemented successfully on-time and the learning experience will be appreciated.

Figures 1 and 2: CAD Design of the Buggy

Technical Overview

Introduction
For all the aims, deliverables and milestones to be achieved the technical specifications of the system need to be clearly identified. In this section the features of all the different parts of the system are discussed. Successful delivery of these will secure that a competitive buggy will be constructed.

Sensor Characterisation
The most important component of the system used to track the position of the line is the reflective sensor. The measurements showed that the TCRT5000 sensor with integrated LED and phototransistor gave a stable and large output voltage when it detected the white line. The change of voltage level was more obvious and significant when compared to the results from the other choices (Figure 3). Therefore, the chosen sensor is the TCRT5000 sensor.


A complete sensor specification includes the height above the line in which the sensors will be placed and the value of the output resistor. The measurements for the selected sensor showed that a height of 2.55 cm gave the most rapid increase in the output voltage between the white and black part. Furthermore, intermediate voltages could be measured between the low and high voltage and as a result at this height the sensor has maximum sensitivity, which will be useful for the processing of the measurements by the microcontroller. Also, data from the experiments demonstrated that the voltage increase was more visible when using a 10 kΩ output resistor in series with the phototransistor and in-between values are available as well. Hence, a 10 kΩ output resistor will be used.
The configuration of the sensors was decided depending on how the irregularities of the track will be dealt with. A straight array of 5 TCRT5000 sensors will be placed at the front of the buggy collecting data for the position of the line (Figure 4). This configuration will ensure that the buggy does not drift away from the line as the outermost sensors can detect a sharp corner or turn and will also be able to deal with line breaks as the sensors will cover a wide range of the track. Finally, the integrated daylight blocking filter of the sensor will deal with the ambient light of the room and the change in the reflectivity of the white line so that these irregularities will not influence the measurements.


Other sensors are also used which measure useful quantities or show the orientation of the buggy. First, a speed sensor uses a quadrature encoder to measure the speed and direction of the gearbox. Additionally, a battery monitor uses a Dallas Integrated Circuit to measure the voltage and the accumulated current of the battery. Also, a current sensor uses an isolating circuit on the motor drive board to measure the current sent to each motor and a Low-Energy Bluetooth module operating in 2.4 GHz will be used to aid the turnaround of the buggy when it reaches the end of the track. Finally, an additional tilt sensor will be used, which is more thoroughly discussed in the “Winning Features” section.
All the mentioned sensors give valuable quantities to the microcontroller which processes the input data and outputs actions depending on the software design of the system.

Software System Design
The software of the system will be designed to monitor the position of the buggy by analysing the data from the sensors and controlling its steering by changing the speed of the wheels.
At first, the constraints of the embedded system software need to be considered. These concern the memory, timing and cost. The memory limitation will not hinder progress because the available memory of 512 KB of flash and 96 KB of SRAM can store a big programme. In terms of timing, when deciding which algorithm to use it is important to bear in mind that the motors should react fast enough to turns or sharp corners. Also, the £40 budget limits the purchase of the additional features to maximise the system’s functionality. However, this amount is enough for the order of components for the buggy.
The implementation of software is based on the operation of the microcontroller getting signals from the various sensors (TCRT5000, speed sensor, battery sensor, Bluetooth, current sensor and tilt sensor) and controlling the two motors with different functions.
The main function of the code monitors the values measured from the leftmost and rightmost sensors and adjusts the current sent to the motors. Multiple functions will be written corresponding to many different use cases. As an example, Stop, GoSlower, ConstantSpeed, ReadSpeed, CalculateVelocity are functions which will

Figure 4: Sensors Geometry be involved in the system’s software. Other functions in the code responding to changes include refinding the line, steering in turns or sharp corners, stopping, overcoming a hill/step, dealing with a Bluetooth signal etc. Finally, the objects involved in the code will be: Motor, TCRT5000, Bluetooth, Control Algorithm, Speed Sensor, Velocity, Battery.
The software will hence adjust the speed of the motors by monitoring it with the quadrature encoders and comparing it with the required value. The appropriate control algorithm will give a better adjustment of the speed.

Control Algorithm Section
The selection for the controller depends on the type of sensor and the configuration of the sensors on the buggy. The configuration of 5 sensors in a straight array will allow the outermost sensors to output voltage levels from which the system understands where the line is relatively to its position.
The Proportional Controller is found to be the most suitable option to control the speed and direction of the wheels. This controller fits perfectly with the configuration of the sensors as it will be comparing the sensors’ output with the reference value and will output the appropriate power difference in the two motors so that steering is effective. A Proportional Controller provides a good control of the speed by controlling the proportionality gain Kp. However, there are issues arising as well. The steady state offset is not eliminated completely which means that the buggy will not be directly above the line. This will not affect the buggy’s performance significantly as the gain will be appropriately set so that the deviation from the line will be insignificant. Hence, the controller will be able to provide rapid corrections and responses.
The control algorithm is also defined. It reads the output value from the sensors and adjusts the steering depending on the values of Kp and the error. More specifically:


The sensors are multiplexed to the same ADC on the STM32 microcontroller and will be sampled one after another with a total sampling time of 5 μs. That means that each sensor will be sampled for 1 μs. This is a rate that the selected microcontroller can keep up with [1]. Using this control algorithm the provided motors will be controlled.

Motor Characterisation
The motors used in the buggy are now fully characterised, after the necessary measurements have been carried out. They will be operated at 5 V and maximum 1.4 A due to overheating. Some important quantities like the armature resistance (1.893 Ω) and the brush voltage (0.0042 V) were extracted and contributed in deriving the two constants for the motor KE (0.0076) and KT (0.0084) with a small error included due to measurement readings. These constants are helpful to find the value of current needed to go up the maximum slope or to set a particular speed on flat surface.
Furthermore, the input torque of 0.012 Nm is not enough to drive the buggy up the maximum slope. Therefore, a gearbox is needed to provide the required torque of 0.1428 Nm. Appropriate calculations showed that the gear ratio needed corresponds to the gear ratio of Gearbox 3 (output/input ratio = 18.75). Hence, this is the selected gearbox.
The current will be adjusted in the transition from the flat surface to the ramp and vice versa so that the torque needs are fulfilled. In the flat surface the current will be adjusted to approximately 0.4 A which will result in a calculated maximum speed of 1.8602 m/s. On the ramp, the current will be approximately 1.2 A which will give a maximum speed of 0.8615 m/s.
In conclusion, the motors are critical for the successful movement of the buggy however additional, innovative features will be added which will contribute to its agility.

Winning Features
Firstly, it is important for the buggy to realise when it is moving in a flat surface or on a ramp. This can be achieved using two tilt sensors one for the uphill and one for the downhill.
Each sensor consists of a mercury switch. When the terrain changes a small amount of the liquid mercury connects the metal electrodes allowing current to pass through. The effect of this will be the adjustment of the current, hence increase in torque on the ramp, and increased speed on the flat surface. The sensors will interface with the microcontroller using a digital input pin.
All the above are combined and placed together on the chassis of the buggy.

Chassis Design
The chassis of the buggy is a single layer of Acetyl with dimensions that adapt with the specifications of the track. The shape of the chassis is a rectangle with a semicircle front end. That way the components and wires on the buggy can be adjusted without getting cut on a sharp edge. The width of the chassis is 14 cm considering the track specifications and its length is about 23 cm. All components are attached on the base with screws. Figure 5 shows the chassis and its dimensions.


Its thickness is decided to be 3 mm as it will reduce the weight and therefore increase the speed. The robustness of the design was examined by carrying out the stress analysis on SolidWorks with the expected load. The load that the base is subject to is 491 g, which includes the battery pack (265 g), the motor drive board (53 g), the microcontroller (35 g), its breakout board (38 g) and wiring (100 g). An insignificant deflection of 0.1 mm and a small value of stress were found, which ensures that the chassis is not likely to significantly bend or break during the race. Different materials were evaluated to choose the best option. After thorough analysis, Acetyl was decided to be the best to use as it is easily accessible and cheap. Also, it will be the lightest material to use for the same volume of chassis. Furthermore, Acetyl is easy and common to laser-cut.
A further discussion on the design reveals that the drivetrain of the buggy is rear-wheel drive which will make steering more efficient and will also improve acceleration and braking of the buggy. As a final point, it is worth noting that the wheels will have the same distance from the centre of the chassis so that steering is smooth in both right and left direction and the distance between them will be as small as possible to make steering faster.

Summary
As a conclusion, all the parts on the buggy are now known and their functionality is completely analysed. The effective communication between them will ensure a successful and competitive performance around the track. At this point, a clear image of the system is shaped. The successful cooperation of the team will guarantee the implementation of all the above features.

Figure 5: 2D Chassis Drawing

Team Organisation

Roles and Responsibilities The roles and responsibilities of the group were set out in the first meeting. These roles were important to set out quickly, so everyone knew their part within the project group. The roles were picked out depending on what members felt most comfortable doing, this approach has also been used when splitting off technical tasks for the design reports. These roles and responsibilities have been a key part of the team’s organisation and have kept the group in line and focussed throughout the first 12 weeks of the project.
Alkinoos - Meeting Organiser
Fed - Journal Writer
Kai - Minute Keeper
Ruoning - Helper
Elvis - Helper

Communications
As soon as the groups were announced, a One Drive folder was set up titled “Embedded Systems Project Group 37” and shared with the entire group (Figure 6). This folder has been integral to the success of the team as all of the documents required to complete tasks such as data sheets and section drafts for the report are shared. It has been an easy way to keep tabs on progress as well as quickly sharing documents that can be accessed. For example, it has been very useful when submitting the individual contribution entries for the weekly journal.


Additionally, a Facebook messenger group chat was created where quick burst of information and decisions can be made straight away. This method of contact was used as a last-minute review before submissions where all members have to confirm that they agree with what will be submitted after the final changes have been made. Where deadlines have been set over a longer period of time, the chat has also proved useful to send reminders as seen in Figure 7 where reminders have been sent out. This has helped the group stay on top of the many deadlines that have been required to meet since the start of the year.

Figure 6: One Drive Folder


The weekly journal is the main source of evidence of meetings as one was created every week covering the progress and next steps discussed in the week. However, the Facebook group chat has also been used to keep record of the meetings, so everyone instantly knows what they need to be doing in the week. Everyone had to submit an individual journal entry by 4pm on the Sunday to their individual weekly journal folder. The person responsible for the weekly journal then edited that week’s journal with everyone’s entry and uploaded the journal to both Blackboard and OneDrive. The format for the journal stayed consistent throughout the weeks as a base template was used. The sections: Action items from last week, Project status, Individual student contributions and other issues were talked about within the weekly journal report to cover what was said during the weekly meetings.

Figure 7: Online Communication


Table 1: Example Weekly Journals for 3 weeks

Meetings and Decision Making Meetings occur on average twice a week. This varies depending on the workload for that week. For example, when an assignment was given from engineering management or an important report deadline was coming up the group would meet more frequently in order to meet the deadlines. Usually, the meetings occur at the start and end of the week, so tasks can be given out at the start and people have enough time to complete them to a high standard before reconvening at the end of the week to assess what has been done and the next progress steps. All decision making has been done diplomatically to make sure the entire group agrees with what needs to be done and when for. By setting realistic time goals we have ensured that our quality of work is high. During our meetings the group discusses, previous deadlines, deadlines needing to be met by the next meeting and a general discussion of everyone’s progress regarding their individual tasks.

Reflection on Success
The team organisation has seemed to be successful as all deadlines have been met on time and to a high standard where everyone has contributed to whatever task was being completed that week. Everyone knows what they have to do for the next meeting due to the Facebook chat being used to remind people about important tasks. This has been one of the main reasons for our group meeting deadlines and working consistently. As everyone met their own personal deadlines the group kept progressing with work without being held back by someone. The OneDrive folder has proved to be incredibly useful during the final group editing meetings for DR1 and DR2 as we can all preview the document at the same time and see markings people were making at once.
The workload has been shared out depending on who feels most comfortable doing which tasks. During the first meeting before a major task is started, everyone is asked which part they want to contribute to. Normally, this will depend on the technical aspects of that section and whether a person feels they can manage the workload and use their knowledge of the subject to complete it. This is believed to be the most diplomatic way of separating out tasks to ensure people are not doing something they do not want to do, which in turn could cause friction in the group. In an effort to spread workload as evenly as possible the roles of assistant leaders were delegated at the same time. These positions were used as helpers to sections and where needed they would contribute their own knowledge to the task.
Within semester 2 we are planning on sectioning tasks to people depending on what they feel they can aid the group best in. As some people prefer or understand better certain aspects of the project, when ordering the tasks in the Gantt Chart we considered these traits to allocate resources. For example, Alkinoos and Elvis having prepared the CAD submission and having an interest in the mechanical aspect of the project, the assembly and soldering will be their main focus. Whilst Federica, Kai and Ruoning, having spent time on the coding and control algorithms, will have the software as their main focus.
There are 4 learning styles we were asked to look at and review each of them to find which position we believed we fit into best. The four styles can be summarised as the Activist, Reflector, Theorist and Pragmatist. The activists “involve themselves fully and without bias in new experiences.” [2] The reflectors “like to stand back to ponder experiences and observe them from many different perspectives to think about it thoroughly before coming to a conclusion.” [2] The theorists “adapt and integrate observations into complex but logically sound theories. They think problems through in a vertical, step-by-step logical way.” [2] The pragmatists “are keen on trying out ideas, theories and techniques to see if they work in practice.” [2] In our group we adopted all 4 learning styles between us.
Alkinoos - Reflector
Federica - Pragmatist
Elvis - Activist
Ruoning - Theorist
Kai - Pragmatist

Planning and Budget

Gantt Chart
According to the timetable of Semester 2, the Gantt Chart is created, as shown in Figure 8.


The arrows in the Gantt chart indicate dependencies: the submission of proposal and final reports depends on writing and editing the drafts. To guarantee the success of submission, a leverage period is set to avoid last-minute problems. Buggy construction depends on the hardware, software and circuit development which will be taking place throughout the first weeks of the semester. This process will hopefully lead to the full buggy integration. The success of technical demonstrations will be guaranteed by practicing and testing hardware and software in the lab sessions at least one week before each technical demonstration. Additionally, two of the group members are responsible for each part, based on their skills, to ensure the completion of the tasks.

Risk Assessment
The possible risks on the Race Day are shown in Table 2. For example, if the buggy is carried improperly, it would fall down and some components may be destroyed. Also, if batteries or the tilt sensors start leaking, people are exposed to toxic substances. Furthermore, if people touch the buggy immediately after the buggy stops running, their hands may get burned due to the overheating of the motors. Finally, if people don’t take care while walking, they may stumble on tracks or

Figure 8: Gantt Chart


equipment on the floor. By listing these risks the necessary control measures will be taken to ensure that everyone stays safe during that day.

Budget
The components that need to be purchased are shown in Table 3. Since the buggy needs 5 TCRT5000 sensors but the freely-issued ones are only two, 3 additional sensors need to be purchased. The same stands for the small PCBs. Two tilt sensors are needed to measure the angle of the heap with two additional ones for back-up.

Table 2: Risk Assessment for Race Day

Table 3: Items to purchase

Total Cost
In the following table the total cost of all the components used is calculated. For the PCB Fabrication a quote was obtained by PCB Train and also an approximate cost for the manufacturing of the chassis was extracted.


References

[1] ST Life Augmented. (2015, Jan). STM32F401xD – xE. Available: https://www.st.com/resource/en/datasheet/stm32f401re.pdf , p. 107, [Accessed: 05-Feb- 2019]
[2] "Honey and Mumford — University of Leicester", Www2.le.ac.uk, 2018. [Online]. Available:
https://www2.le.ac.uk/departments/doctoralcollege/training/eresources/teaching/theories/honey-mumford (https://www2.le.ac.uk/departments/doctoralcollege/training/eresources/teaching/theories/honey-mumford) , [Accessed: 16- Dec- 2018]
[3] PCB Train. Available: https://www.pcbtrain.co.uk/quote-order , [Accessed: 05-Feb- 2019]
[4] Available: https://www.bearingboys.co.uk/Acetal-/Acetal-Sheet-500mm-x-500mm-x-3mm-NaturalWhite-37837-p (https://www.bearingboys.co.uk/Acetal-/Acetal-Sheet-500mm-x-500mm-x-3mm-NaturalWhite-37837-p) , [Accessed: 05- Feb- 2019]

Table 4: Total Cost of components and buggy

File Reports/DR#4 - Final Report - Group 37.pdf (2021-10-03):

## Embedded Systems Project

## DESIGN REPORT #4

## Title: Final Report

## Group Number: 37

Group members name: | ID Number | I confirm that this is the group’s own work.
Federica Donald | 10095518 | ☒
Alkinoos Sarioglou | 10136315 | ☒
Elvis Taimal Gongora | 10146823 | ☒
Kai Guo | 10201372 | ☒
Ruoning Mi | 10431554 | ☒

## Tutor: Dr. Emad Alsusa Date: 08/05/2019

Contents

Executive Summary – Introduction

The Embedded Systems Project is a useful learning experience for the members of the team, as they are faced with the challenge to design and construct an autonomous robot, while being an active part of a team.
All of the above is achieved by keeping in mind the main aim of the project: the buggy needs to follow a white line around a track autonomously, while overcoming obstacles. During the full duration of the project, a very well organised procedure is followed by the entire team to ensure objectives are achieved on time and the development has the anticipated progress. In the first semester, the required knowledge is acquired by the group members on how the buggy navigates around the white line. Also, time is spent on planning and designing what components will be used meanwhile a CAD model is created for the buggy chassis. The second semester includes assembly of all the components and programming the microcontroller for the buggy to run efficiently around the track. This report concludes the Embedded Systems Project and summarises the work undertaken on planning, designing, building and operating the buggy the group created. There are 4 main parts: the final system’s components summary, the team organization, the budget and the analysis of the heats.
Firstly, the components used are the most crucial aspect of the system as they ensure its successful operation. These include mechanical, electronic, control and software components. The main mechanical components used are: DC Motors, Gearboxes, Encoders, Wheels and Tyres and the Chassis. In terms of electronic components, the reflective sensors on the stripboard, the motor drive board, the microcontroller board and the Bluetooth module are most significant. Furthermore, the sensor, speed PID controllers and the Bluetooth guarantee a successful control of the movement. Finally, as far as the software is concerned, libraries, classes and objects with different functions of the algorithm are implemented to complete the correct functionality. Overall, the buggy successfully integrated the sensor circuit, the motors on the chassis and demonstrated great communication between components. The following CAD design (Figure 1) and the actual picture of the buggy (Figure 2) show the configuration of components on the chassis. The chassis is shaped as a semicircle at the front and rectangle at the back which makes it good-looking and getting cut on a sharp edge is avoided. It can also be seen that the motor drive and the microcontroller board are on top while the battery pack and the stripboard with the sensors underneath.


Figure 1: CAD Design


In addition to that, the code carried out the objective of the project successfully by implementing the control algorithm for the correct adjustment of power for the motors depending on the readings from the sensors. However, some changes were required like the connections on the microcontroller board to be able to accommodate the LCD screen.
For all the above to materialise, good organisation of the team and a suitable plan was required. The plan included a time schedule for all the main objectives to be achieved on time. These include report writing, CAD and PCB Design, Interface of Motors and Sensors, Assembly of the System, Successful Movement and Steering and the Track Length Estimation Algorithm. Some changes did occur during the implementation of the plan, e.g. no PCB fabrication and no tilt sensors implementation, which were related to timing issues. Furthermore, the 5 members of the group were divided into 2 teams to achieve efficient division of workload. One team worked on the hardware and the other on the software part of the buggy. A Gantt Chart was also created to keep track of the project’s progress and ensure all deliverables are achieved on time. A critical analysis of the team’s performance reveals that this was accomplished due to the strong organisation skills of the team, which resulted in high scoring on the technical demonstrations and the reports with few points missing. For that reason, changes in a future project would include more productive breaks and more productive use of the budget. Also, difficulties that arose did not affect the normal operation of the team.
When it comes to budget, apart from the freely-provided components, the spend was 18.92£ in total. That results in an overall cost of £252.51 for the whole system. However, towards the actual value of the buggy the hard work of five people for 1 year should be counted. For this reason, the price that the buggy would be sold for is much higher. The high price is supported by the good performance in the Heats and the Final Race.
Before the heats, the team performed many tests to check the full operation of the buggy and completed minute corrections. These involved improvements of the turnaround function and increase of the speed. The evidence of testing proves the development of these parts. The first attempt in the Heats was unsuccessful, because of a problem in the turnaround function. However, the buggy completed the

Figure 2: Picture of the Buggy track in 20 seconds in the second attempt and qualified in the Final Race. In the Final Race, the successful features of the buggy like the fast and smooth movement boosted its performance and achieved the Best Track Length Estimation Award, while the problematic features (big size, messy wiring) did not disrupt the correct operation of the system. The components summary gives a better insight into these features.

Final System Components Summary

Mechanical components
The mechanical components of the system can be summarised as:
- Motors
- Encoders
- Gearbox
- Wheels/Tyres
- Chassis
- Screws, nuts, spacers
- Ball castor
- Battery case

It is obvious that the most crucial part is the motor module, which is composed of a DC motor, a quadrature encoder and a gearbox. This was chosen during the development of the buggy among three options. Gearbox 3 was selected as this produced the torque needed for the buggy to climb on a slope of 18°. The motor module is attached to a rubber tyre through a gearbox. The chassis was developed by measuring the components placed on it and calculating their weight distribution so that no significant bending occurs. During the assembly procedure the electrical components, the ball castor #955, the motors with the rims, screws, nuts and spacers were placed on the chassis. Finally, a battery case was added since there was no original way of fixing the batteries safely on the design.

Electronic components
The electronic components of the system can be summarised as:
- Motor drive board
- Switch
- Sensors
- Resistors
- Darlington Array
- Stripboard
- Bluetooth module
- Microcontroller board
- LCD screen

The motor drive board was powered by the rechargeable batteries which together generated a maximum of 10 V for the buggy to work properly. This board controls the current and voltage output to the motors depending on the speed set by the microcontroller board. On the NUCLEO microcontroller board the code was transferred for processing in order for it to send the suitable electrical signals to the electrical components of the buggy for efficient operation of the system. Furthermore, a switch was used to control the ON and OFF condition of the system. Additionally, the contribution of the electronic components used on the stripboard was integral to the success of the sensor implementation. More specifically, the 6 resistors of 68 Ω, the 6 resistors of 10 kΩ, the ULN2003A Darlington Buffer that was used to draw less current from the microcontroller board to turn on the LEDs and most importantly the 6 TCRT5000 line sensors. This type of sensor was chosen among several options since it was the most accurate and sensitive when detecting the white part and contains a daylight blocking filter. More complex components include the Bluetooth module which was used to receive a signal and force the turnaround of the robot. Finally, an LCD screen was added to display measurements that the buggy computed, like the track length estimation.

Control components
The control components of the system can be summarised as:
- Sensor and speed PID controllers
- Proportional, Derivative, Integral Action
- Kp ,Kd ,KI
, Error
- Bluetooth
The control algorithm of the system guarantees a correct adjustment of the motor speeds depending on the readings from the sensors, so that the buggy navigates correctly above the line. For the algorithm, two PID controllers were used. First of all, a sensor PID controller was used to monitor the error of the position of the buggy when compared to the centre of the white line. The proportional, derivative and integral action depending on their constants provided corrections to the position of the buggy by converting this error into a speed action for the motors. Therefore, a smooth movement above the line was ensured. Furthermore, a speed PID controller read measurements from the encoders in order to fix the speed of the motors with the same value on the straight section and adjust the speed when the buggy deals with an uphill or a downhill. The Bluetooth module applies a different kind of control by controlling the turnaround. The signal was sent from a mobile device and determined when the turn will occur. After that, the normal line-following algorithm resumed its operation.

Software components
The software components of the system can be summarised as:
- Libraries
- Classes
- Member Functions
- Data Members
- Objects
- Main Code
The software part of the system is of great importance as it controls the operation of all the components and determines whether the communication is effective between them. It uses different parts to achieve this. First of all, the code uses functions or parts of code from pre-written libraries. These provided useful functionality for different components like the encoders and the LCD screen. Then, classes were constructed which helped with the modular design of the code making it easier to debug. Each class represents a different part of the system, e.g. motor, Bluetooth etc. It includes all the important information for this particular part (data members)

and many member functions that it can be used with. One example is the class of Motor which contains data members like bipolar, PWM etc. and member functions like constant speed, forward rotation, backward rotation etc. Then, in the main code, objects of the classes were created to represent the objects of the actual system, e.g. MotorLeft and MotorRight etc. All the functions performed by the objects were connected in the main-code and interacted with each other giving rise to the operation of the whole system as an entity.

Parts that worked well and Changes The parts of the system that were fully-functioning can be summarised as:
- Stripboard with reflective sensors
- Motors
- Communication of components with microcontroller board
- Chassis design
- Software Design

First of all, the stripboard including the sensor circuit performed exceptionally in the sensor demonstration and therefore it was mounted on the chassis without any further adjustments. Also, the performance of the motors was satisfactory as they responded to the full range of speeds and reacted quickly to the commands of the microcontroller. This suggests that the communication of the components and the software design was accomplished, as the sensors would send the readings to the microcontroller, which would process the outputs and adjust the speed of the two motors to control the direction of the buggy. Finally, the chassis design was successful as it managed to accommodate all the components required and without causing significant problems to the movement.
However, there were things that required change during the project.
These can be summarised as:
- No tilt sensor used
- Connections on the microcontroller
- Addition of LCD screen to display measurement of distance

To begin with, tilt sensors were not used on the system in the end due to timing issues. These were planned to detect incline or decline and help the speed control algorithm adjust the speed of the motors. Changes were also made in the connections of the microcontroller board since some pins which were initially used were needed for the LCD screen. The screen proved to be crucial for the system as the results of track length measurements would be displayed on it. As a result, a change in the connections had to be completed and wiring diagrams had to be redrawn.

Summary
In conclusion, the organisation of the components reviewed in this section was done in steps during the progress of the project development in order to observe changes and the interaction between the parts of the system. The improvements and next steps would then be decided. This would not be possible without a very strong team organisation and planning that took place within the team.

Team Organisation and Planning

Summary of Project Objectives
The main aim of the project was to create an autonomous line-following buggy that will follow a white line placed in the middle of a track. The objectives to complete along the way include:
- Reports including the Motor and Sensor Characterisation, the Proposal and the Final Report
- CAD Design and Chassis Fabrication
- PCB Design and Fabrication
- Interface of Motors
- Interface of Sensors including the tilt sensors
- Buggy Assembly
- Successful movement / Steering
- Code Development including the track length estimation code

The milestones of the project were the following:
- Report deadlines throughout the entire year
- Technical Demonstrations including motor control, sensor interface, steering demonstration and the heats
- PCB Fabrication Submission
- Final Report
- Race Day

Objectives changed mainly throughout the second semester as the project became more practical driven. The first change of objective was not creating the PCB for the sensors. This was decided not to be completed as the group considered it an unnecessary use of resources as the stripboard had been completed to a high standard and it worked. Additionally, the time constraint the group had placed on the integration of both hardware and software to ensure the buggy was ready for each technical demonstration requirement became an issue for completing the PCB. Secondly, the tilt sensors were not implemented into the buggy system. These were interfaced and tested however the group decided that the possibility of improving speed control would be sacrificed for the added complexity and time cost this would place.

Organisation of the Team
Organisation included Alkinoos, Elvis and Kai on the hardware team whilst Federica and Ruoning were on the software team. Towards the end of the project, once hardware was completed, Alkinoos joined the software team to help with the last technical demonstrations and final adjustments and refinements.
The main changes to the Gantt Chart included the timescale of the objectives set. Apart from the main compulsory deliverables, most of the objectives took up more time than anticipated. However, this was not a huge issue as the team had split into two groups for this reason. Everyone could be participating and working on other parts of the project in order for the group to act in a parallel fashion and keep the flow of work going. This improved the organisation, but it led into a few communication issues between departments as comes with a divisional type structure of working.

Critical Analysis
From a critical analysis point of view, it should be pointed out that all deliverables were achieved on time. This is mainly due to the fact that objectives were set for deliverables before the deadlines to ensure that they were completed early. The group completed the technical demonstrations to the best of its ability given the time available, with only a few points missing or not being completed fully. However, the majority were completed successfully resulting in high scoring. The reports were also completed on time due to high organisation skills with the group having a strict policy to deliver reports: Compromising of bullet points to get the members thinking about the content of the sections usually required to be complete 2 weeks before deadline; then, an initial flowing and fully written draft usually required to be complete a week before the deadline and a final draft to be complete 2 or 3 days before the report deadline allowing for any errors to be negated. This procedure resulted in improved performance in the reports from one time to another and high scoring in the last reports.

Difficulties
The only difficulties present within the group have been illnesses, interview and exam absences. These problems were resolved and overcome by the rest of the group continuing as planned as the person absent was only missing for 1 or 2 days.

Summary
The group worked very well as a team, with clear leaders set out from the beginning, a grounded communication network and clarified deadlines so no tensions arose. If team work and productivity were to be improved, it would be suggested to include incentives such as breaks and/or praise. The Draugiem Group found that the “top ten percent most productive employees didn’t actually work any more hours than anybody else, they took more breaks” [1] stated on Forbes about how stress reduces productivity. Therefore, if as a group there were clear breaks used for creative purposes (allowed through the timetabling of the semester) the group could perhaps have been more productive in the long run throughout the project. Another improvement would be the more efficient use of the available budget with more additional components purchased for added features in the buggy. It is understandable that the budget and the overall cost of the robot have been important aspects of the project.

Budget vs. Outturn

Spend Costs
In the building stage of the project some free parts were provided. However, additional components were required for the system to be complete. For that reason, 6 Tilt sensors, 5 mini PCBs and 3 TCRT sensors were ordered. The cost is 18.92£ in total. The prices and quantities of the ordered components are listed in Table 1. However, this price is above what was actually needed. This was because the white box of the team containing all the important components was taken away mistakenly for a month and the group did not have the required components to complete the system. Therefore, some parts needed to be reordered resulting in more budget usage. Also, due to time limits and technical reasons, tilt sensors were not used in the end. Nevertheless, the cost was well within the £40 limit for the project.

Item | Quantity | Price Per Item (£) | Cost (£)
Tilt Sensors | 6 | 2 | 12
Mini PCBs | 5 | 1 | 5
TCRT Sensors | 3 | 0.64 | 1.92
| | Total: | £18.92
Table 1. Price for Ordered Parts

Buggy Price Proposition
The total cost for the buggy, including the freely-provided parts and the ordered parts, is shown in Table 2.
Item | Quantity | Cost (£)
Resistors | 12 | 1.2
TCRT5000 | 6 | 3.84
HM-10 Bluetooth Module | 1 | 16.36
Chassis Material | 1 | 42
Front Wheel | 1 | 2.5
Rubber Tyre | 2 | 2.9
Motors | 2 | 14.22
Gearbox | 2 | 14
NUCLEO-F401RE | 1 | 15
Application Shield | 1 | 33.09
Motor Drive Board | 1 | 30
Sensor Mini PCBs | 12 | 12
Battery Holder | 1 | 3.5
Batteries | 8 | 16
Insulation Tape | 1 | 2
Cable Ties | 3 | 0.6
Stripboard | 1 | 3.5
Tilt Sensors | 6 | 12
Chassis Fabrication | 1 | 27.8
| | Total: £252.51
Table 2. Total Cost of the Buggy

As Table 2 shows, the total cost for the buggy is £252.51. If this was connected to a real business, more factors than the total cost of the components would be considered. These include the time and effort spent on designing, programming and constructing the system. According to the National Minimum Wage Standard, minimum wage for people aged from 21 to 25 is £7.38 per hour [2]. Assuming total time spent on the project to be 200 hours, the minimum wage for each person is £1476. The total wage for the 5-people-team is £7380. To make a profit, the selling price is increased to £8000, so the profit of each buggy is £367.49. The high selling price is also justified by the buggy’s accuracy on estimating the length of a track since it received the prize for Best Track Length Estimation on the Race Day and its result was within ±0.1 cm error. The buggy can be sold for a higher price if more functions are added to it based on customers’ needs and preferences.

Analysis of Heats

Preparation for the Heats
The full construction of the system was implemented when all the extra components were ordered and received. The technical demonstrations showed that the functionality of all the components was competent. Following the last technical demonstration, which included following a small track of the line, either straight or curved, the team had to perform minute corrections to the system in the hardware or the software part to ensure an efficient and quick performance around the track for the heats.
In the steering demonstration, the buggy moved successfully in the straight and curved parts of the line and it was able to use the encoders to implement the speed control algorithm. The controlled stop worked perfectly too. However, there was a problem with the turnaround, as the buggy would receive the Bluetooth signal but after reversing direction it would miss the line. Therefore, it was obvious that improvements had to be made on this part when preparing for the heats.
The weeks before the heats all the work done was based on improving the code regarding the turnaround. It would be crucial to have a reliable algorithm running after the 180° turn. The software team worked in trying different versions of the turnaround function and results were improved significantly using a section of the track provided in the labs. Evidence of results of improvement can be seen in Table 3 in Section 5.2. At the same time, the efforts of the team were focused on increasing the speed of the buggy. The PWM of the motors in the straight section was increased from 70% to 85% of the period in the bipolar mode. Also, the speed in the turns was boosted from 65% PWM to 80%. These changes caused some problems especially in the sharp turns where the buggy would miss the line many times. The solution was to re-tune the sensor PID controller by increasing the values of Kp and Kd. A crucial part to mind was to make sure that it can complete the sharp curves. These turns contributed significantly when deciding the values of the constants. The change of the parameters led to important observations on the movement of the buggy during testing which are mentioned in Table 4 (Section 5.2). The ultimate goal was to make the buggy run with the mentioned values of PWM smoothly above the line.
A few days before the heats, a problem came up with the battery charger. The batteries could not be charged, resulting in the team swapping them every time they were running low. However, this problem did not affect the time schedule of the team. On the last day before the heats, a test of the whole system was performed. The tests on the provided tracks proved that the buggy could follow the line and therefore all the components were fully-functioning.

Testing and Evidence of Results

- Turnaround Function Improvement The improvement of the turnaround involved developing and testing the function which would be called at the turnaround point by Bluetooth. Table 3 includes different versions of the function which were tested (from oldest to newest) but also observations on the performance.
Turnaround Function | Observations and Improvements
void turnaround (void) { Motor2.write(0.5f); Motor1.write(0.5f); wait(1); Motor2.write(0.8f); Motor2.write(0.4f);} | The buggy stops and turns smoothly. Need to add the Bluetooth

| functionality and to detect the line after the reverse turn.
else if (hm10.readable()) { d = hm10.getc(); if(d == 'A'){ MotorOne.write(0.8f); MotorTwo.write(0.4f); wait(3); } } | Τhe buggy now performs a turnaround when the Bluetooth signal is sent. It turns around but the wait function is not useful to detect the line afterwards.
void turnaround () { MotorOne.write(0.5f); MotorTwo.write(0.5f); wait(1); while (angle<180) { MotorOne.write(0.7f); MotorTwo.write(0.3f); leftwheel.showspeed1(); rightwheel.showspeed2(); angle1=leftwheel.angle1(); angle2=rightwheel.angle2(); angle=angle1-angle2; pc.printf("%.3f",angle); } angle1=0; angle2=0; angle=0; setspeed();} | The buggy is not able to detect when the angle becomes 180° due to problem with the encoders. The microcontroller cannot perform the expected functionality correctly with this function. Another way of detecting the line needs to be developed.
void turnaround () { MotorOne.write(0.5f); MotorTwo.write(0.5f); wait(1); MotorOne.write(0.7f); MotorTwo.write(0.3f); wait(2); while ((out1.read()<0.36) && (out2.read()<0.36) && (out3.read()<0.36) && (out4.read()<0.36) && (out5.read()<0.36) && (out6.read()<0.36)) { MotorOne.write(0.7f); MotorTwo.write(0.3f); } setspeed();} | The buggy performs the required functionality and the code seems to be suitable. However, the turning is fast and when trying to detect the line again sometimes it is not successful and turning continues. Some factors like the sensor values and the “wait” functions need to be improved.
void turnaround () { MotorOne.write(0.5f); MotorTwo.write(0.5f); wait(1); MotorOne.write(0.7f); MotorTwo.write(0.3f); wait(1); while ((out3.read()<0.8)) { MotorOne.write(0.6f); MotorTwo.write(0.3f); } MotorOne.write(0.5f); MotorTwo.write(0.5f); wait(0.7); setspeed();} | The condition for re-finding the line is improved as the central sensor is exactly on the line when the buggy stops after the turnaround. However, when detecting the line instead of following the line, the buggy turns abruptly, misses the line and stops. The microcontroller finds difficulty in transitioning to the original function. The transition needs to be improved.

void turnaround () {
MotorOne.write(0.5f);
MotorTwo.write(0.5f);
wait(1);
MotorOne.write(0.7f);
MotorTwo.write(0.2f);
wait(0.5);
while ((out3.read()<0.45)) { MotorOne.write(0.7f);
MotorTwo.write(0.15f);
}
MotorOne.write(0.5f);
MotorTwo.write(0.5f);
wait(1);
while (!((out1.read()<0.36) && (out2.read()<0.36) && (out3.read()<0.36) && (out4.read()<0.36) && (out5.read()<0.36) && (out6.read()<0.36))) {

values=(3)*out1.read()+(2)*out2.read()+1*out3.read()+(-1)*out4.read()+(-2)*out5.read()+(-3)*out6.read(); error=ref-values;
integral = integral + error; derivative = error - lasterror; lasterror=error;
if ((error>0.75)|| (error<-0.75)) {
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

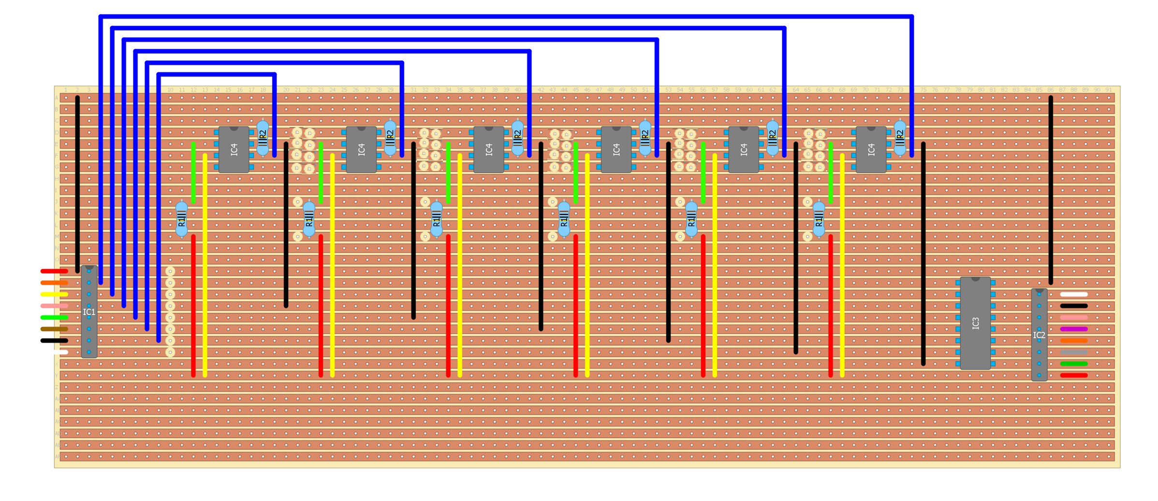
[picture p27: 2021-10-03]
Schematics/Stripboard Layout Diagram.png

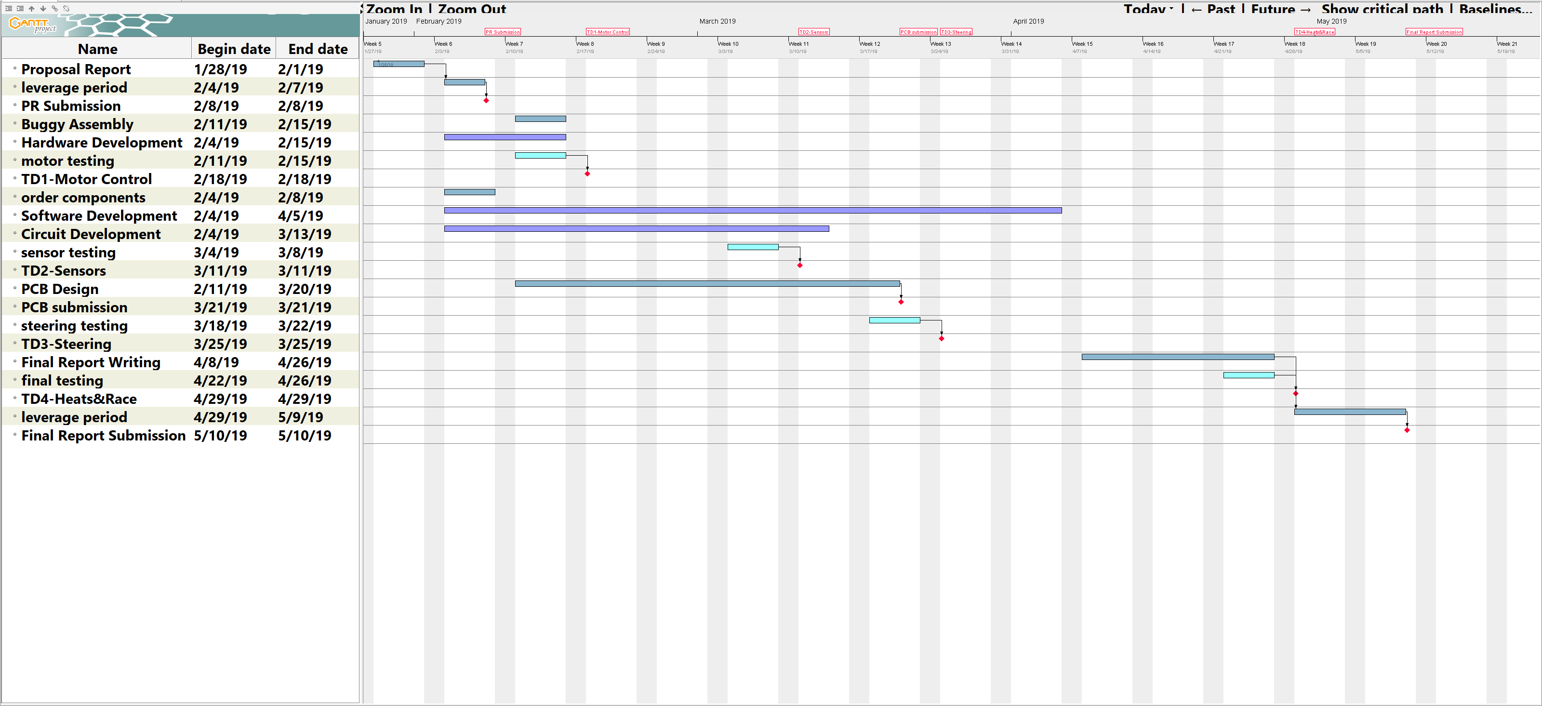
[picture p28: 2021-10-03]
gantt chart.PNG

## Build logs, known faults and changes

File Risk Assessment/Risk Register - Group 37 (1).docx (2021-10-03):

Group Number: | 37 | | Submission Date: | 06-11-2018
Group Members: | Federica | Alkinoos | Elvis | Ruoning | Kai

Project Risk | Severity | | | Potential | | | Score (Severity x Potential) | Mitigation Measures
| L | M | H | L | M | H | L=1, M=2, H=3
Not within budget | L | | | L | | | 1 | Plan the budget ahead and ensure the values of components are known and considered before ordering
Components aren’t delivered | | M | | L | | | 2 | Ensure we know exactly what we are ordering and place order well within the deadline
Missed deadlines | | | H | L | | | 3 | Keep up to date with meetings and minutes to make sure everyone knows the deadlines
Conflict in team | | M | | L | | | 2 | Put equal effort into the project to relive stress and bring issues up when they occur
Incorrect information for equipment | | | H | | M | | 6 | Double check data sheets. Ensure at least 2 people are looking at them as an error check
Insufficient knowledge to complete a task | L | | | | M | | 2 | Delegate tasks to people’s strengths and provide support for those not as confident in certain areas
Conflict of design opinions | | M | | | M | | 4 | Ensure everyone’s voice is accounted for to decide the best option for the buggy
Components forgotten | L | | | | | H | 3 | Make sure everyone understands what is happening, when and what equipment they are required to bring
Soldering fumes | | | H | L | | | 3 | Ensuring the extraction fan is on and above the component being soldered
Burning | | | H | L | | | 3 | Properly health and safety training completed and first aid on hand
Electrocution | | | H | L | | | 3 | Make sure to turn off when not in use in laboratories
Tripping | L | | | | M | | 2 | Be aware of surroundings and cautious when around multiple buggies are being tested

We confirm that all group members participated in the production of this risk register: Yes

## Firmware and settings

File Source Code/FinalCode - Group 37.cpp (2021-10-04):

#include "mbed.h"
#include "QEI.h"
#include "C12832.h"

#define sensorKP    0.12
#define sensorKD    0.15
#define sensorKI    0

#define speedKP     0.02
#define speedKD     0
#define speedKI     0.001


#define RATE 0.1
#define wheelradius 0.04 // in m
#define PI 3.14159265358979323846

DigitalOut Enable(PB_8);
C12832 lcd(D11, D13, D12, D7, D10);
QEI wheel1(PB_13,PB_14,NC,256);
QEI wheel2(PC_9,PB_7,NC,256);
DigitalOut sensor1(PB_4);
DigitalOut sensor2(PB_5);
DigitalOut sensor3(PB_3);
DigitalOut sensor4(PA_10);
DigitalOut sensor5(PA_9);
DigitalOut sensor6(PC_7);

AnalogIn out1(PC_0);
AnalogIn out2(PC_1);
AnalogIn out3(PC_2);
AnalogIn out4(PC_3);
AnalogIn out5(PA_4);
AnalogIn out6(PB_0);


class Bipolar {
private:
    DigitalOut Bi;
public:
    Bipolar(PinName pin): Bi(pin) {}
    void tru(void) {Bi = 1 ;}
};

class On {
private:
    DigitalOut pins;
public:
    On(PinName pin): pins(pin) {}
    void tru(void) {pins = 1 ;}
};

class motors {
private:
    PwmOut MotorOne;
    PwmOut MotorTwo;
public:
    motors(PinName l, PinName r) : MotorOne(l), MotorTwo(r) {}
    void setperiod(){
        MotorOne.period(0.0002f);
        MotorTwo.period(0.0002f);
        }
    void constant (){
        MotorOne.write(0.95f);
        MotorTwo.write(0.95f);
        }
    void left () {
        MotorTwo.write(0.8f);
        MotorOne.write(0.6f);
        }
    void right () {
        MotorTwo.write(0.6f);
        MotorOne.write(0.8f);
        }
    void stop () {
        MotorOne.write(0.5f);
        MotorTwo.write(0.5f);
        }  
};

class encoder1 {
private:
    float w1,current1,newangle1,oldangle1,dth1,s1,w3,v3;
    Ticker tttq;
    int sample1;
public:
    encoder1 () {tttq.attach(callback(this,&encoder1::getnumber),0.001),s1=0,w1=0,w3=0,v3=0;}
    
    
    void getnumber (void) {
        sample1=wheel1.getPulses();
    }
    
    int returnsample1 (void) {
        return sample1;
    }
    
    void showspeed1 (void) {
        current1 = sample1;
        newangle1=((current1/(2*256))*360)*((2*PI)/360);
        oldangle1 = 0;
        dth1=newangle1-oldangle1; //angle in rad
        s1+=dth1*wheelradius;
        w1=dth1/0.1; //angular speed in motor shaft in rad/s
        w3=w1*0.053333; //angular speed in wheel shaft in rad/s
        v3=w3*wheelradius; //linear speed of the wheel
        wheel1.reset();
    }
    
    float distancel (void) {   
        return s1;
    }
    
    float speed1 (void) {
        return w3;   
    }
    
    float angle1 (void) {
        return dth1;   
    }
};

class encoder2 {
private:
    float w2,current2,newangle2,oldangle2,dth2,s2,w4,v4;
    Ticker ttt;
    int sample2;
public:
    encoder2 () {ttt.attach(callback(this,&encoder2::getnumber2),0.001),s2=0,w2=0,w4=0,v4=0;}
    
    void getnumber2 (void) {
        sample2 = -wheel2.getPulses();
    }
    
    int returnsample2 (void) {
        return sample2;
    }
    
    void showspeed2 (void) {
        current2 = sample2 ;
        newangle2=((current2/(2*256))*360)*((2*PI)/360);
        oldangle2 = 0;
        dth2=newangle2-oldangle2; //angle in rad
        s2+=dth2*wheelradius;
        w2=dth2/0.1; //angular speed in motor shaft in rad/s
        w4=w2*0.053333; //angular speed in wheel shaft in rad/s
        v4=w4*wheelradius; //linear speed of the wheel
        wheel2.reset();
    }
    
    float distancer (void) {
           return s2;
    }
    
    float speed2 (void) {
           return w4;
    }
    
    float angle2 (void) {
        return  dth2;
    }
    
};


class Bluetooth {
private:
    Ticker ok;
    char c;
    Serial hm10;
    PwmOut MotorOne,MotorTwo;
public:
    Bluetooth(PinName l, PinName r, PinName T, PinName R) : MotorOne(l), MotorTwo(r), hm10(T,R) {ok.attach(callback(this, &Bluetooth::signal), 0.001),hm10.baud(9600);}
    
    void signal (void) {
        if(hm10.readable()){
            c = hm10.getc();
                if(c == 'A'){
                    turnaround();
                }
        }
    }
    void turnaround (void) {
        
        //led=1;
        MotorOne.write(0.5f);
        MotorTwo.write(0.5f);
        wait(1);
        MotorOne.write(0.8f);
        MotorTwo.write(0.4f);
    }
};

class control : public encoder1,encoder2 {
private:
    float values, error, controlaction,difference;
    int ref;
    encoder1 leftwheel;
    encoder2 rightwheel;
    Serial hm10;
    float integral;
    float derivative;
    float kd;
    float ki;
    float kp;
    Serial pc;
    Ticker ttt,dist;
    enum state {normal,bluetooth};
    state st;
    int sample1,sample2;
    float dth1,dth2;
    float angle,angleone,angletwo,lasterror,angulardiff;
    float error2,controlaction2,kp2,kd2,ki2,lasterror2,integral2,derivative2;
    char d;
    PwmOut MotorOne,MotorTwo;
public:
    control (PinName T, PinName R, PinName l, PinName r, PinName a, PinName b) : hm10(T,R), MotorOne(l), MotorTwo(r),pc(a,b) {ttt.attach(callback(this,&control::bluetoothsignal),0.0001),ref=0, integral=0, derivative=0,sample1=0,sample2=0,dth1=0,dth2=0,kd=sensorKD,ki=sensorKI,kp=sensorKP,kp2=speedKP,kd2=speedKD,ki2=speedKI,lasterror=0,angulardiff=0,integral2=0,derivative2=0,lasterror2=0,st=normal,angle=0,angleone=0,angletwo=0,hm10.baud(9600);}
    
    void bluetoothsignal() {
        if (hm10.readable()) {
                d = hm10.getc();
                if(d == 'A'){
                    turnaround();
                }
                if (d=='B'){
                    stop();
                    }
            
        }
        
    }
    
    
    void setspeed(){
        if ((out1.read()<0.36) && (out2.read()<0.36) && (out3.read()<0.36) && (out4.read()<0.36) && (out5.read()<0.36) && (out6.read()<0.36)){ //values need to be tested
            MotorOne.write(0.5f);
            MotorTwo.write(0.5f);
        } //CONTROLSTOP
        
        
        else {
            values = (3)*out1.read()+(2)*out2.read()+1*out3.read()+(-1)*out4.read()+(-2)*out5.read()+(-3)*out6.read();
            error=ref-values;
            integral = integral + error;
            derivative = error - lasterror;
            lasterror=error;
            if ((error>0.75)|| (error<-0.75)) { //initially 0.75
                controlaction = (kp*error)+(ki*integral)+(kd*derivative);
                MotorOne.write(0.78f - controlaction); //init 0.75
                MotorTwo.write(0.78f + controlaction); //init 0.75
            }
            else if (error>2.7 || error<-2.7) {
                controlaction = (kp*error)+(ki*integral)+(kd*derivative);
                while ((out3.read()<0.78)) {
                    MotorOne.write(0.85f - controlaction);
                    MotorTwo.write(0.85f + controlaction);
                }
            }
            else {
                constantspeed();   
            }
        }
        /*rightwheel.showspeed2();
        leftwheel.showspeed1();
        lcd.printf("%.3f\n\n", (leftwheel.distancel()+rightwheel.distancer())/2);  */
        wait(0.0001);
    }
    
    void setperiod(){
        MotorOne.period(0.0002f);
        MotorTwo.period(0.0002f);
    }
    
    void constantspeed () {
        difference = - leftwheel.speed1() + rightwheel.speed2();
        error2 = - difference;
        integral2 = integral2 + error2;
        derivative2 = error2 - lasterror2;
        lasterror2=error2;
        controlaction2 = (kp2*error2)+(ki2*integral2)+(kd2*derivative2);
        MotorOne.write(0.8f - controlaction2); //init 0.75
        MotorTwo.write(0.8f + controlaction2); //init 0.75
        wait(0.001);
    }
    
    void turnaround () {
        MotorOne.write(0.5f);
        MotorTwo.write(0.5f);
        wait(1);
        MotorOne.write(0.7f);
        MotorTwo.write(0.2f);
        wait(0.5);
        while ((out3.read()<0.45)) {
            MotorOne.write(0.7f);
            MotorTwo.write(0.15f);
        }
            MotorOne.write(0.5f);
            MotorTwo.write(0.5f);
            wait(1);
        while (!((out1.read()<0.36) && (out2.read()<0.36) && (out3.read()<0.36) && (out4.read()<0.36) && (out5.read()<0.36) && (out6.read()<0.36))) {
            values = (3)*out1.read()+(2)*out2.read()+1*out3.read()+(-1)*out4.read()+(-2)*out5.read()+(-3)*out6.read();
            error=ref-values;
            integral = integral + error;
            derivative = error - lasterror;
            lasterror=error;
            if ((error>0.75)|| (error<-0.75)) {
                controlaction = (kp*error)+(ki*integral)+(kd*derivative);
                MotorOne.write(0.75f - controlaction);
                MotorTwo.write(0.75f + controlaction);
            }
            /*else if (error>2.7 || error<-2.7) {
                controlaction = (kp*error)+(ki*integral)+(kd*derivative);
                while ((out3.read()<0.78)) {
                    MotorOne.write(0.65f - controlaction);
                    MotorTwo.write(0.65f + controlaction);
                }
            }*/
            else {
                constantspeed();   
            }
        }
        MotorOne.write(0.5f);
        MotorTwo.write(0.5f);
        wait(5);
    }
    
    void stop() {
     MotorOne.write(0.5f);
     MotorTwo.write(0.5f);
     wait(5); 
    }
     
};  


Bipolar B1(PB_10);
Bipolar B2(PB_9);
motors m(PC_6,PC_8);
encoder1 leftwheel;
encoder2 rightwheel;
control pidsensors(PA_11, PA_12, PC_6, PC_8,USBTX, USBRX);
Bluetooth ble(PC_6, PC_8, PA_11, PA_12);
Serial pc(USBTX,USBRX);


int main(void) {
    lcd.cls();
    Enable = 0;
    lcd.locate(20,20);
    B1.tru();
    B2.tru();
    sensor1=1;
    sensor2=1;
    sensor3=1;
    sensor4=1;
    sensor5=1;
    sensor6=1;
    pidsensors.setperiod();
    wait(0.5);
    Enable=1;
    while(1){
        pidsensors.setspeed();     
    }
    
}

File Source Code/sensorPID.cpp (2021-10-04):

class control {
private:
    float values, error, controlaction;
    int ref;
    float integral;
    float derivative;
    float kd;
    float ki;
    float kp;
    float lasterror;
    PwmOut MotorOne,MotorTwo;
public:
    control (PinName l, PinName r) : MotorOne(l), MotorTwo(r) {ref=0, integral=0, derivative=0, kd=0, ki=0,kp=0.15, lasterror=0;}
    void setspeed(){
        values = (3.2)*out1.read()+(2.1)*out2.read()+1*out3.read()+(-1)*out4.read()+(-2)*out5.read()+(-3)*out6.read();
        error=ref-values;
        integral = integral + error;
        derivative = lasterror - error; //derivative=(lasterror - error)/dt ADD dt
        controlaction = (kp*error)+(ki*integral)+(kd*derivative);
        lasterror=error;
        MotorOne.write(0.6f - controlaction);
        MotorTwo.write(0.6f + controlaction);
        wait(0.001);
    }
    
    void setperiod(){
        MotorOne.period(0.0002f);
        MotorTwo.period(0.0002f);
    }
    
    void controlstop(){
        if ((out1.read()<0.05) && (out2.read()<0.05) && (out3.read()<0.05) && (out4.read()<0.05) && (out5.read()<0.05) && (out6.read()<0.05)){ //values need to be tested
            MotorOne.write(0.5f);
            MotorTwo.write(0.5f);
            wait;
        }
    }
     
};  

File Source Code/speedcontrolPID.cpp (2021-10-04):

#include "mbed.h"
#include "QEI.h"
#include "C12832.h"

#define wheelradius 0.04 // in m
#define PI 3.14159265358979323846

C12832 lcd(D11, D13, D12, D7, D10); 
QEI wheel1(PB_13,PB_14,NC,256);
QEI wheel2(PC_9,PB_7,NC,256);
Serial pc(USBTX,USBRX);

class Bipolar {
private:
    DigitalOut Bi;
public:
    Bipolar(PinName pin): Bi(pin) {}
    void tru(void) {Bi = 1 ;}
};

class encoder1 {
private:
    float w1,current1,newangle1,oldangle1,dth1,s1,w3,v3;
    Ticker tttq;
    int sample1;
public:
    encoder1 () {tttq.attach(callback(this,&encoder1::getnumber),0.1),s1=0,w1=0,w3=0,v3=0;}
    
    
    void getnumber (void) {
        sample1=wheel1.getPulses();
    }
    
    int returnsample1 (void) {
        return sample1;
    }
    
    void showspeed1 (void) {
        current1 = (float) sample1;
        newangle1=((current1/(2*256))*360)*((2*PI)/360);
        oldangle1 = 0;
        dth1=newangle1-oldangle1; //angle in rad
        s1+=dth1*wheelradius;
        w1=dth1/0.1; //angular speed in motor shaft in rad/s
        w3=w1*0.053333; //angular speed in wheel shaft in rad/s
        v3=w3*wheelradius; //linear speed of the wheel
        wheel1.reset();
        /*lcd.locate (0,3);
        lcd.printf("Left wheel:");
        lcd.locate (0,20);
        lcd.printf("%.3f",s1); */
    }
    
    float distancel (void) {   
        return s1;
    }
    
    float speed1 (void) {
        return v3;   
    }
    
};

class encoder2 {
private:
    float w2,current2,newangle2,oldangle2,dth2,s2,w4,v4,*stwo;
    Ticker ttt;
    int sample2;
public:
    encoder2 () {ttt.attach(callback(this,&encoder2::getnumber2),0.1),s2=0,w2=0,w4=0,v4=0,stwo = &s2;}
    
    void getnumber2 (void) {
        sample2=-wheel2.getPulses();
    }
    
    int returnsample2 (void) {
        return sample2;
    }
    
    void showspeed2 (void) {
        current2 = (float) sample2;
        newangle2=((current2/(2*256))*360)*((2*PI)/360);
        oldangle2 = 0;
        dth2=newangle2-oldangle2; //angle in rad
        s2+=dth2*wheelradius;
        w2=dth2/0.1; //angular speed in motor shaft in rad/s
        w4=w2*0.053333; //angular speed in wheel shaft in rad/s
        v4=w4*wheelradius; //linear speed of the wheel
        wheel2.reset();
        /*lcd.locate (70,3);
        lcd.printf("Right wheel:");
        lcd.locate (70,20);
        lcd.printf("%.3f",s2); */
    }
    
    float distancer (void) {
        return s2;
    }
    
    float speed2 (void) {
        return v4;
    }
};
    
class speedcontrol : public encoder1,encoder2 {
private:
    float kp2,ki2,kd2,error2,integral2,derivative2,controlaction2,lasterror2;
    float difference,ref;
    PwmOut MotorOne,MotorTwo;
public:
    speedcontrol(PinName l, PinName r) : MotorOne(l),MotorTwo(r) {lasterror2=0,ref=0,integral2=0,derivative2=0,controlaction2=0,kp2=1,ki2=0,kd2=0,difference=0;}   
    
    void constantspeed () {
        difference = speed1() - speed2();
        if (difference!=0) {
            error2 = ref - difference;
            integral2 = integral2 + error2;
            derivative2 = lasterror2 - error2;
            controlaction2 = (kp2*error2)+(ki2*integral2)+(kd2*derivative2);
            lasterror2 = error2;
            MotorOne.write(0.75f - controlaction2);
            MotorTwo.write(0.75f + controlaction2);
        }
        else {
            MotorOne.write(0.75f);
            MotorTwo.write(0.75f);     
        }
        wait(0.0001);
    }
        
    
};


int main () {
    encoder1 leftwheel;
    encoder2 rightwheel;
    speedcontrol s(PB_10,PC_8);
    lcd.cls();
    float diff,averagespeed,distance;
    DigitalOut Enable(PC_7);
    Enable = 1;
    Bipolar B1(PB_8);
    Bipolar B2(PB_9);
    PwmOut Motor1(PB_10);
    PwmOut Motor2(PC_8);
    B1.tru();
    B2.tru();
    Motor1.period(0.0002f); //0.4second period
    Motor2.period(0.0002f);
    Motor1.write(0.5f);
    Motor2.write(0.5f);
    while (1) {
        leftwheel.showspeed1();
        rightwheel.showspeed2();
        s.constantspeed();
        diff = leftwheel.speed1() - rightwheel.speed2();
        averagespeed = (leftwheel.speed1() + rightwheel.speed2())/2;
        pc.printf("Difference: ");
        pc.printf("%.5f\n",diff);
        pc.printf("\n");
        wait(1);
        
    }
}
   
    
    

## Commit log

2021-10-04 Rename encoders.txt to Source Code/encoders.txt
2021-10-04 Rename sensorPID.txt to Source Code/sensorPID.txt
